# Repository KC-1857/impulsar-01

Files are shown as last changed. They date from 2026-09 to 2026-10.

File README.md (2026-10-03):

# Impulsar-01 — Local Home AI Station


[]()

[Русская версия](README-RU.md)

Open-source home AI station: a voice assistant and smart home control on a single-board computer.

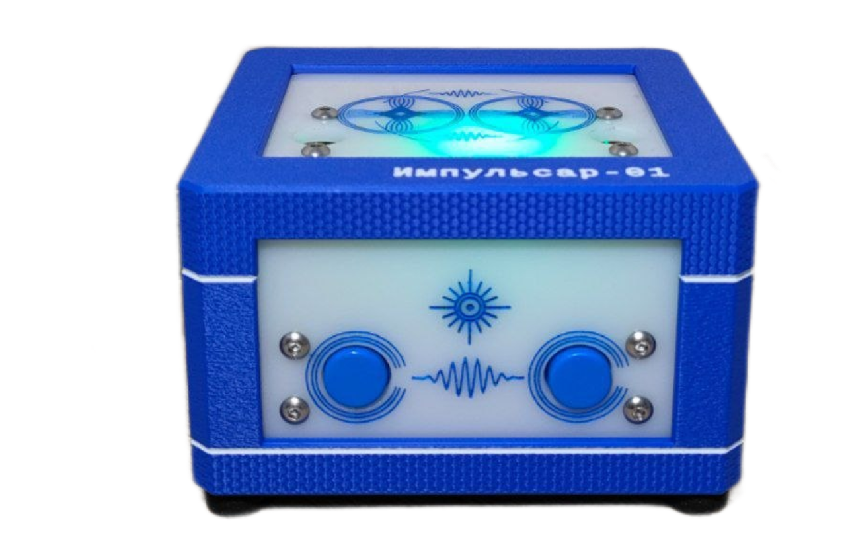
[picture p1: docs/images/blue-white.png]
Prototype


## Features

- On-device Russian speech recognition in real time
- Voice control of Zigbee devices using a fixed command vocabulary
- LED status indication (listening, command, ready, error)
- Event log for monitoring and diagnostics

## Hardware

- Orange Pi CM4 (Rockchip RK3566) single-board computer
- Microphone expansion board
- USB Zigbee coordinator

## Enclosure

[Rev06 enclosure](mechanical/impulsar-01-rev06/README.md): printable STL, laser-cut
acrylic DXF/SVG, fit-test coupons, an editable FreeCAD model, STEP exports and
standalone generators. The variant directory includes all source geometry and can
be built independently, without printer-specific profiles. See the [manufacturing guide](mechanical/impulsar-01-rev06/MANUFACTURING.md)
and [enclosure catalogue](mechanical/README.md). Physical fit, cooling and drop
resistance still require prototype testing.

## Documentation

Project documentation lives in [`docs/`](docs/):

- [Vision & Scope](docs/vision-ru.md) — product vision, MVP scope, success criteria
- [SRS](docs/srs-ru.md) — technical specification: requirements, use cases, acceptance tests
- [Backlog](docs/backlog-ru.md) — user stories with priorities and estimates
- [User story map](docs/user-story-map-ru.md) — scenarios and MVP slice
- [Hardware reference](docs/hardware-ru.md) — Orange Pi CM4 platform details
- [Glossary](docs/glossary-ru.md) — hardware terms
- [Diagrams](docs/diagrams/) — PlantUML sources (context, use cases, components)

## Image

The working image is available via the link:

[Image link](https://drive.google.com/file/d/1G7m_2_bZuDXotqwk8EMmxWDe1scBuL78/view)

## Contributing

Please read [CONTRIBUTING.md](CONTRIBUTING.md) before submitting changes.

## License

Licensed under [GPL-3.0](LICENSE).

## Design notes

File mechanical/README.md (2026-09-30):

# Корпуса Импульсар-01

| Вариант | Назначение |
| --- | --- |
| [Northern lights — 01](Northern%20lights%20-%2001/) | Исходные STL и DXF первого корпуса |
| [Импульсар-01 rev06](impulsar-01-rev06/README.md) | Самодостаточный вариант: корпус 102 × 95 × 60 мм, акрил 2,85 мм, винтовая сборка; исходники, генераторы, STL, лазерные контуры, пробники и FreeCAD |

Готовность файлов к цифровой обработке не означает выполнения приёмки корпуса
по [SRS §4.3.8 и TC-05](../docs/srs-ru.md). Компоновку электроники, доступ
к разъёмам, охлаждение и прочность необходимо проверить на собранном образце.

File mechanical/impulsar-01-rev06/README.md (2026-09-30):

# Импульсар-01 — корпус rev06

Корпус **102 × 95 × 60 мм**: три печатные детали, пять панелей акрила **2,85 мм**,
пазы **3,00 мм**, два винта M3×50 и съёмная планка верхнего акрила.

Самодостаточный вариант корпуса: каталог содержит исходные данные, параметры,
генераторы и контрольные модели этого дизайна. Его можно скопировать отдельно
и собрать без остальных каталогов проекта. Геометрия не привязана к модели
принтера, размеру его рабочего поля или конкретному слайсеру.

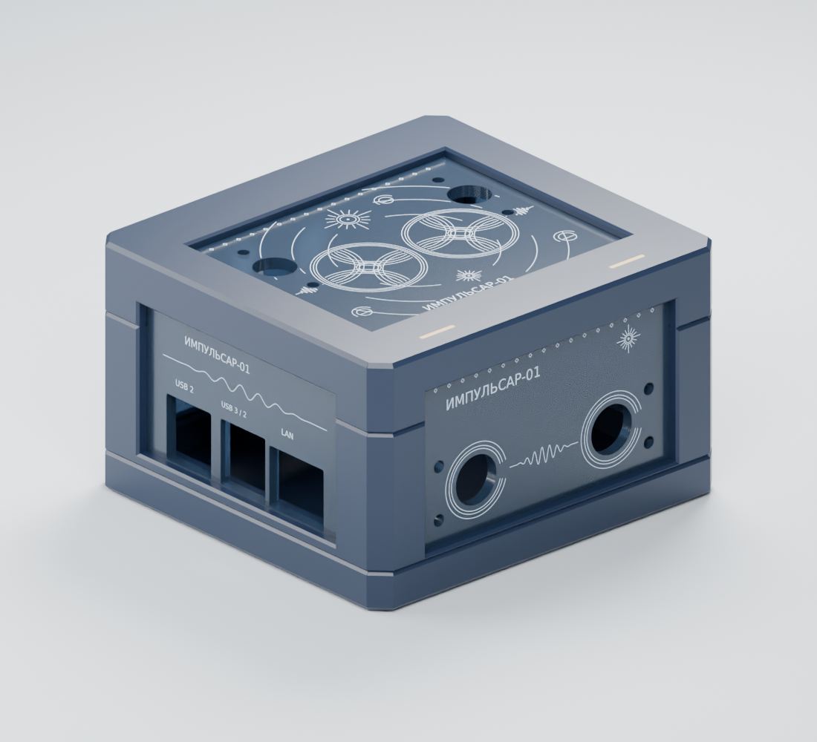
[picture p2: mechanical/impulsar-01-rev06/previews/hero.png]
Корпус rev06


## Что открыть

- **Для изготовления:** [инструкция и крепёж](MANUFACTURING.md), [STL для печати](print/),
  [пробники](coupons/), [лазерные DXF/SVG](laser/), [многоцветная крышка 3MF](multicolor/lid_multicolor.3mf).
- **Для редактирования:** [FreeCAD](cad/enclosure.FCStd), [нейтральные STEP](cad/step/),
  [вид нативной CAD-модели](cad/preview.png).
- **Для просмотра:** [3D-сборка GLB](assembly/impulsar06.glb), [разнесённый вид](previews/exploded.png).
- **Конструкция и исходные данные:** [DESIGN.md](DESIGN.md).
- **Результаты проверки:** [STL, FreeCAD и STEP](validation/README.md).

`print/`, `assembly/`, `coupons/`, `laser/`, `multicolor/` и изображения — контрольный комплект
корпуса Импульсар-01 rev06. Его хеши записаны в [reference/assets.sha256.json](reference/assets.sha256.json).
`assembly/` содержит координаты сборки, **не ориентации для печати**.

## Автономная пересборка

Команды выполняются **из этого каталога `impulsar-01-rev06/`**. Все исходные данные
находятся внутри него; доступ к сети при сборке не требуется. Зависимости
устанавливаются заранее:

```bash
python3 -m venv .venv
.venv/bin/python -m pip install -r requirements.txt
.venv/bin/python src/build_mesh.py
```

Результат: локальный `build/mesh/` — сборочные и печатные STL, пробники, многоцветный 3MF,
копии лазерных контуров, параметры, сравнение с исходником и новый отчёт проверок.
Превью и GLB являются сохранёнными иллюстрациями корпуса rev06; сборщик их
не обновляет. После изменения конструкции они могут перестать соответствовать ей.

Параметры задаются в [design.json](design.json). Для экспериментов используйте
копию и `--config путь/к/design.json --output build/мой-вариант`.
`parameters.json` в результатах — отчёт, а не входной файл. Лазерные контуры являются
входными исходниками; изменение толщины не меняет их плоскую геометрию и имена.
После изменения толщины обозначения `2p85` требуют отдельного обновления.

Пути к исходникам и результатам по умолчанию определяются относительно каталога
варианта, независимо от текущего рабочего каталога. Генераторы разрешают вывод
в локальный `build/` или отдельный внешний каталог и защищают исходные данные
и готовый комплект от перезаписи.
Обновление готовых файлов выполняется после проверки результатов и просмотра diff.

## FreeCAD

Требуется FreeCAD **1.1.x** с Python API. Проверено на FreeCAD 1.1.3 / Python 3.14.
Интерпретатор должен совпадать с Python ABI установленного FreeCAD.
Пример для ALT Linux (путь библиотеки в других дистрибутивах отличается):

```bash
PYTHONPATH=/usr/lib64/freecad/lib .venv/bin/python src/build_cad.py
```

Результат: `build/cad/` — `enclosure.FCStd`, STEP отдельных деталей
и сборки, STL из той же CAD-геометрии в сборочных и печатных координатах.
Пересчёт дерева из нескольких сотен операций может занять десятки минут.

Модель содержит нативные эскизы, выдавливания, лофты, цилиндры и булевы операции.
Открытие и редактирование FCStd не требуют установки скриптов проекта.
В таблице **Parameters**, столбец B, доступны толщина акрила, ширина пазов,
радиусы проходных отверстий, отверстий планки и направляющих саморезов.
После изменения выполнить пересчёт документа. Геометрия крепежа — номинальные
огибающие без резьбы. Контуры панелей редактируются в исходных DXF и пересобираются.

CAD восстановлена по исходным STL и измеренным плоским сечениям: это отдельное
параметрическое представление rev06. Круглые элементы CAD аналитические, поэтому
они могут немного отличаться от исходной полигональной аппроксимации.
Оригинальные производственные STL сохранены отдельно от экспортов CAD.
Изменения в GUI FreeCAD **не записываются автоматически в design.json или Python**;
для воспроизводимой правки перенесите значения в конфигурацию/генератор.

## Проверки и физическая приёмка

Сборщик STL проверяет замкнутость и связность сеток, разницу объёмов с исходником,
сопряжения деталей, проход крепежа, дискретные траектории снятия крышки и установки
панелей, удержание верхнего акрила, ожидаемый натяг саморезов и входа гаек.
Отчёты контрольного комплекта находятся в `validation/`, новые создаются в `build/`.

После генерации CAD проверьте повторное открытие FCStd, импорт STEP, сетки,
сравнение с исходником и сопряжения. `--edit-check` дополнительно меняет пять
размеров таблицы и пересчитывает документ; тестовые изменения не сохраняются:

```bash
PYTHONPATH=/usr/lib64/freecad/lib .venv/bin/python src/verify_cad.py --edit-check
```

Цвета и прозрачность готового FCStd настроены в GUI FreeCAD; генератор воспроизводит
геометрию и дерево операций. Превью CAD также сохраняется отдельно от геометрии.

Проверка контрольных сумм, исходных сеток и многоцветного 3MF:

```bash
.venv/bin/python src/verify_assets.py
```

Отчёт создаётся в `build/audit/`.

Статус физической посадки: **не подтверждена**. Окна CM4 оценены по фотографии;
начните с пробника панели и узлов крепления. Полная электроника, провода и охлаждение
не представлены в сборке. Тепловые испытания и падение с 1 м не проводились.
Цифровые проверки подтверждают геометрию, но не заменяют испытаний собранного корпуса.

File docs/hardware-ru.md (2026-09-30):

# Одноплатный компьютер Orange Pi CM4 (RK3566) — справочник по аппаратной части

Версия документа: 0.2

Назначение: справочная информация по аппаратной платформе стенда — базовой плате Orange Pi, модулю CM4 (SoM) и SoC Rockchip RK3566.
Требования к Системе — в [docs/srs-ru.md](./srs-ru.md)

Механическая часть: [корпус rev06](../mechanical/impulsar-01-rev06/README.md),
модели FreeCAD/STEP, STL, лазерные контуры и инструкция изготовления.
Компоновка полной электроники и охлаждение требуют проверки на прототипе.

## 1. Глоссарий

- eDP (Embedded DisplayPort) – интерфейс для внутренних дисплеев, выведен на дополнительные контакты модуля CM4, но не на базовую плату;
- MIPI DSI (Display Serial Interface) – скоростной интерфейс для подключения дисплеев; на RK3566 доступны 4 линии, но базовая плата разводит только 2
- MIPI CSI (Camera Serial Interface) – интерфейс для подключения камер, аналогично DSI, на базовой плате выведено 2 линии
- PMIC (Power Management Integrated Circuit) – микросхема управления питанием, на модуле CM4 используется RK809-5
- TRM (Technical Reference Manual) – техническое руководство по процессору, содержащее детальное описание регистров, блоков и программирования
- VPU (Video Processing Unit) – блок для ускорения кодирования и декодирования видео; в RK3566: декодирование до 4K@60fps (H.265/H.264/VP9), кодирование до 1080p@60fps

## 2. Спецификация

### 2.1. Базовая плата Orange (Base Board)
| Компонент | Характеристика |
|---|---|
| **Видеовыходы**| 1× Micro HDMI 2.0 (4K@60fps), 1× MIPI DSI (2 линии) |
| **Камера** | 2× MIPI CSI (2 линии каждый) |
| **Сеть** | 1× Gigabit Ethernet (RJ45) |
| **USB** | 1× USB 3.0 Host, 2× USB 2.0 Host, 1× USB 2.0 OTG |
| **Хранилище** | Слот MicroSD (TF), разъём M.2 M-Key (SATA3 или PCIe 2.0 ×1 NVMe) |
| **Аудио** | 3.5 мм комбинированный разъём (вход/выход) |
| **Расширение** | 40-контактная колодка (GPIO, UART, I2C, SPI, PWM); напряжение 1.8 В или 3.3 В (переключается джампером) |
| **Охлаждение** | 4-контактный разъём для вентилятора (5 В) |
| **Кнопки** | MASKROM, RECOVERY, RESET |
| **Питание** | USB Type-C, 5 В / 3 А |
| **Размеры (PCB)** | 85 × 56 мм |
| **Масса** | 46 г |

### 2.2. Модуль Orange Pi CM4 (SoM)
| Компонент | Характеристика |
|---|---|
| **SoC** | Rockchip RK3566 |
| **Оперативная память**  | 2 ГБ LPDDR4 |
| **Встроенная память** | 8 ГБ eMMC |
| **Беспроводная связь**  | Wi-Fi 5 (802.11ac), Bluetooth 5.0 (чип AP6256) |
| **Ethernet PHY** | YT8531C (10/100/1000 Мбит/с) на модуле |
| **PMIC** | Rockchip RK809-5 |
| **Размеры (PCB)** | 55 × 40 мм |
| **Разъёмы** | 2× 100-контактных + 1× 24-контактный (совместимость с Raspberry Pi CM4 по основным сигналам) |
| **Выведенные сигналы**  | HDMI 2.0, MIPI DSI (4 линии), MIPI CSI (4 линии), eDP, SATA3/PCIe, USB 3.0, USB 2.0 (×3), аудио, GPIO|
| **Операционная система** | Linux (4.19.232) — стоковый BSP-образ вендора; целевая ОС проекта — ALT Linux, ядро 6.18 (SRS НФ-10.1) |

### 2.3. Чип: Rockchip RK3566

### 2.3.1. Общие сведения
| Параметр | Значение |
|---|---|
| **Модель** | Rockchip RK3566 |
| **Тип** | Система на кристалле (SoC) для мультимедийных и IoT-приложений |
| **Техпроцесс** | 22 нм |
| **Корпус** | BGA-565 (15.5 × 14.4 мм) |

### 2.3.2. Центральный процессор (CPU)
| Параметр | Значение |
|---|---|
| **Архитектура** | ARMv8-A (64-bit) |
| **Ядра** | 4 × Cortex-A55 |
| **Максимальная частота** | 1.8 ГГц |

### 2.3.3. Графический процессор (GPU)
| Параметр | Значение |
|---|---|
| **Модель** | ARM Mali-G52 2EE |
| **API** | OpenGL ES 1.1/2.0/3.2, OpenCL 2.0, Vulkan 1.1 |
| **2D-ускорение** | Встроенный аппаратный 2D-ускоритель |

### 2.3.4. Видеопроцессор (VPU)
| Параметр | Значение |
|---|---|
| **Декодирование** | 4K@60fps (H.265/HEVC, H.264, VP9) |
| **Кодирование** | 1080p@60fps (H.265/H.264) |

### 2.3.5. Нейронный процессор (NPU)
| Параметр | Значение |
|---|---|
| **Модель** | RKNN NPU |
| **Производительность** | 0.8 TOPS (INT8) |
| **Поддерживаемые фреймворки** | Caffe, TensorFlow, TFLite, ONNX, PyTorch, Keras, Darknet |

### 2.3.6. Интерфейсы памяти и хранения
| Параметр | Значение |
|---|---|
| **Оперативная память** | DDR3/DDR3L/DDR4, LPDDR3/LPDDR4/LPDDR4X (до 8 ГБ) |
| **Хранилище** | eMMC 5.1, SATA 3.0, SPI NOR/NAND Flash |

### 2.3.7. Высокоскоростные интерфейсы
| Интерфейс | Характеристика |
|---|---|
| **Дисплей** | HDMI 2.0a (4K@60), MIPI DSI (4 линии), eDP 1.3, RGB/LVDS; поддержка двух независимых дисплеев |
| **Камера** | MIPI CSI (4 линии / 2×2 линии), 8M ISP с HDR |
| **PCIe** | PCIe 2.1 ×1 (1 линия) |
| **SATA** | SATA 3.0 (1 порт) |
| **USB** | 1× USB 3.0 Host, 2× USB 2.0 Host, 1× USB 2.0 OTG |
| **Ethernet** | 1× Gigabit Ethernet (GMAC) |
| **Аудио** | 8-канальный I2S/TDM, 2× 2-канальный I2S, 8-канальный PDM, S/PDIF выход |

### 2.3.8. Программная поддержка (со стороны чипа)
| ОС | Примечание |
|----|---|
| Android 11 | Официальный BSP от Rockchip |
| Linux (ядро 5.10 / 6.1) | BSP-ядро Rockchip с полной поддержкой NPU/VPU. Например, Linux 5.10.160-rockchip-rk356x под архитектуру arm64|
| Linux (mainline 6.6+) | Частичная поддержка (GPU — Panfrost; VPU/NPU — ограничены) |

### 2.4. Драйверы и прошивки

Состав драйверов и прошивок стенда (нормативные требования — [docs/srs-ru.md](./srs-ru.md), п. 4.3.9).

- WiFi (модуль AP6256, чип BCM4345/9): драйвер `brcmfmac`; файлы прошивки `/lib/firmware/brcm/brcmfmac43456-sdio.bin`, `brcmfmac43456-sdio.txt`, `brcmfmac43456-sdio.clm_blob`. Допускается обобщённая прошивка при совпадении ревизии чипа; board-specific файл `brcmfmac43456-sdio.xunlong,orangepi-cm4-v1.4.bin` не обязателен.
- Аудио (ReSpeaker 2-Mic HAT, WM8960): драйверы `snd-soc-wm8960` и кодек `wm8960`.
- SPI (APA102 LED HAT): драйвер `spidev`, устройство `/dev/spidev3.0`.
- GPIO (кнопка ASR): `gpiod`/libgpiod (userspace).

Проверка: `lsmod`, `dmesg`, `ls /lib/firmware/brcm`, `aplay -l`, `ls -l /dev/spidev3.0`, `python3 -c "import gpiod"` (в выводе `lsmod`/`dmesg` искать `brcmfmac`, `wm8960`, `spidev`).

Прошивки и проприетарные бинарные файлы в репозитории проекта не хранятся — поставляются в составе образа или пакетов.

## 3. Распиновка 40-контактной колодки (GPIO)

### 3.1. Пины SPI и сопутствующие

- 3 : GPIO4 B4 I2C2 SDA
- 5 : GPIO4 B5 I2C2 SCL

- 8  : UART2 TX
- 10 : UART2 RX

- 13 : GPIO 4 A0
- 15 : GPIO 4 A2
- 16 : GPIO 4 A3
- 18 : GPIO 4 A1
- 22 : GPIO 4 A4

- 19 : SPI3 MOSI 
- 21 : SPI3 MISO
- 23 : SPI3 CLK

- 24 : GPIO4 A6 / SPI3_CS0
- 26 : GPIO4_A7 / SPI3_CS1

- GND: 6, 9, 14, 20, 30, 34, 35, 39
- VCC: 1, 17

## 4. Ссылки

- Техническое руководство Rockchip RK3566 (TRM) — rockchip.fr / Rockchip Open Source wiki: https://opensource.rock-chips.com/wiki_RK3566
- Руководство пользователя Orange Pi CM4 — официальный сайт производителя: https://orangepi.org (раздел документации CM4)
- Сборка BSP Orange Pi — репозиторий orangepi-build: https://github.com/orangepi-xunlong/orangepi-build

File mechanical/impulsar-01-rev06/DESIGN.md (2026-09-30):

# Разработка корпуса Импульсар-01 rev06

Rev06 — вариант корпуса для проекта «Импульсар-01»: печатные основание, крышка
и съёмная планка, пять акриловых панелей и винтовое соединение половинок.

## Исходные данные

- Два базовых STL для построения основания и крышки находятся в `source/`.
  Их контрольные суммы сохранены в [reference/source.sha256.json](reference/source.sha256.json).
- [design.json](design.json) задаёт параметры генераторов rev06.
- `laser/` содержит плоские контуры резки и гравировки панелей.
- `src/source_profiles.json` хранит измеренные плоские сечения базовых STL.
  Они воспроизводятся командой
  `python3 src/extract_profiles.py` из каталога варианта;
  результат создаётся в локальном `build/profiles/`.

## Представления конструкции

`src/geometry.py` описывает конструкцию с двумя геометрическими реализациями:
сеточной для STL и нативной для FreeCAD. Модель FreeCAD содержит эскизы,
операции построения и связи с таблицей параметров. STEP и CAD-STL экспортируются
из одной и той же нативной геометрии.

Контрольный комплект изготовления находится в `print/`, `assembly/`, `coupons/`,
`laser/` и `multicolor/`; его параметры — в `reference/parameters.json`, контрольные
суммы 44 файлов комплекта и иллюстраций — в
[reference/assets.sha256.json](reference/assets.sha256.json).
Экспорты нативной модели хранятся отдельно в `cad/`; численные различия двух
представлений и результаты проверок приведены в [validation/](validation/README.md).

Дизайн включает тёмно-синие печатные детали, акриловые панели, гравировку
и два золотистых акцента на крышке. 3MF хранит геометрию и цвета трёх частей
крышки без настроек оборудования. Контуры гравировки находятся в `laser/`.

Каталог самодостаточен после установки зависимостей: соседние варианты корпуса
и корень репозитория для сборки не используются. Команды и порядок изменения
параметров приведены в [README](README.md), изготовление и сборка — в
[MANUFACTURING.md](MANUFACTURING.md).

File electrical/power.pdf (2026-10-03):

V+ | GND
1 | 2

X1

V+ | GND
1 | 2

X2

SA1

Рисунок 1 – Схема электрическая подключения клеммных блоков X1 и X2

## ПЕРЕЧЕНЬ ЭЛЕМЕНТОВ

Поз. обозначение | Наименование | Кол. | Примечание
X1, X2 | Клеммный блок 2-контактный | 2
SA1 | Выключатель кнопочный | 1

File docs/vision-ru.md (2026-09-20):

# Видение и границы проекта (Vision & Scope)

Версия документа: 0.1 

 Связанные документы: 

 [SRS (техническое задание)](./srs-ru.md), 

 [Бэклог](./backlog-ru.md), 

 [Карта пользовательских историй](./user-story-map-ru.md)

## 1. Введение

### 1.1. История контекста

Коммерческие домашние голосовые ассистенты построены на проприетарных облачных сервисах. Устройство записывает речь пользователя, но обрабатывают голос сервера производителя. Логика исполнения сценариев прописана в закрытой экосистеме. Работоспособность устройства зависит от доступности облака и оплаченной подписки. Для пользователя это означает невозможность работать с устройством без интернета и абонентской платы.

Технически задача сводится к запуску модели распознавания речи и обработке команд. Одноплатный компьютер подбирается под минимальную мощность, достаточную для распознавания речи на открытых моделях (GigaAM, Whisper). Поддержка открытого протокола Zigbee позволяет управлять устройствами "умного" дома. Одно из ограничительных условий проекта - минимальная стоимость комплектующих.

Для реализации программной части полезно использовать минимально необходимую проектную документацию, включая требования и сценарии использования. 

### 1.2. Постановка проблемы

В сообществе открытых проектов существуют продукты класса "Домашняя станция". Данный продукт решает следующие проблемы:

- адаптация под условия России: доступные компоненты электроники, лицензии на программы, модели распознавания русской речи;
- минимальная коммерческая стоимость продукта и возможность собрать его своими руками;
- формализованные требования и документация;

### 1.3. Цель документа

Определить видение продукта, его границы, заинтересованные стороны, потребности верхнего уровня, ограничения и критерии успеха. Детальные
требования фиксируются в SRS ([docs/srs-ru.md](./srs-ru.md)), план работ — в бэклоге ([docs/backlog-ru.md](./backlog-ru.md)) и карте пользовательских историй ([docs/user-story-map-ru.md](./user-story-map-ru.md)).

## 2. Видение продукта

### 2.1. Формулировка видения

Пользователь получает устройство с голосовым, кнопочным и электронным интерфейсом для управления Zigbee-устройствами. Первый релиз — портированная на одноплатный SoC система с микрофонным модулем, с установкой компонентов в корпус.

### 2.2. Минимальное рабочее решение (MVP)

Обязательные компоненты MVP:

1. Embedded Linux на одноплатном компьютере;
2. Детекция речевой активности;
3. Распознавание речевых команд в реальном времени;
4. Интеграция с Zigbee-протоколом через USB-адаптер;
5. Закрытый корпус с выводом физических (кнопки, LED), голосовых (микрофонный модуль), электронных (USB) интерфейсов;

## 3. Заинтересованные стороны и пользователи

### 3.1. Заинтересованные стороны

- мейнтейнер проекта;
- технические энтузиасты;
- opensource-сообщество;
- контрибьюторы (участники) проекта;
- пользователи AI-станции;
- поставщики компонент железа (SoC, модули);
- upstream AI-моделей;
- upstream ОС;

### 3.2. Пользовательские роли

- пользователь — говорит команды;
- администратор — проводит диагностику;
- разработчик — собирает проект, вносит изменения.

## 4. Потребности и функции верхнего уровня

- Ф1. Локальное распознавание речи: Система должна распознавать команды в реальном времени;
- Ф2. Дальняя и тихая речь: Система должна распознавать речь на дистанции от 1 до 5 м;
- Ф3. Управление Zigbee-устройствами:
  - Ф3.1. Система должна сопоставлять распознанный текст командам из словаря;
  - Ф3.2. Система должна исполнять команду на исполнительном устройстве (реле, лампы, датчики) с поддержкой Zegbee-протокола;
- Ф4. Индикация состояния: Система должна индицировать фазы работы светодиодом;
- Ф5. Автономность:
  - Ф5.1. Система должна самовосстанавливаться после сбоев;
  - Ф5.2. Система должна работать без подключения к Интернет;

## 5. Ограничения продукта

- Платформа: Orange Pi CM4, SoC RK3566 (4 ядра ARM Cortex-A55, GPU Mali-G52), ASR выполняется на CPU, тяжёлые модели не применяются;
- ОС: семейство ALT Linux (embedded-сборка), ядро 6.18;
- Память и накопитель: объём ОЗУ и eMMC/MicroSD ограничен;
- Аудиотракт: ReSpeaker 2-Mic Pi HAT (кодек WM8960); характеристики микрофонной матрицы задают дальность распознавания; шумоподавление — программное;
- Zigbee: поддержка адаптера;
- Лицензии: GPLv3 и совместимые лицензии; модели с лицензиями, допускающими использование в продукте;
- Бюджет: минимальная стоимость компонент;
- Портирование на другие SoC в текущем MVP не предполагается;
- Многопользовательская идентификация по голосу отсутствует;
- Доступ в интернет отсутствует;
- Веб-интерфейс отсутствует, только VUI;
- Выход звука отсутствует;
- Синтез речи отсутствует;
- LLM отсутствует;

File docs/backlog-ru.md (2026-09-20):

# Бэклог пользовательских историй

Версия документа: 0.1

Связанные документы: [Видение и границы](./vision-ru.md), [SRS](./srs-ru.md),
[Карта историй](./user-story-map-ru.md)

## 1. Назначение и правила ведения

Бэклог — упорядоченный список историй. Правила:
- Детализация средняя; истории оценимы, к ним поставлены приоритеты; бэклог заполняется из обратной связи;
- Каждая история небольшая, независит от других историй, несет ценность для пользователя, тестируемая;
- Приоритизация: Must — без истории релиз не выполним; Should — важная, но релиз возможен без неё; Could — желательная; Won't — исключена из текущих релизов;
- Готовность: критерии приёмки выполнены, результат зафиксирован в CHANGELOG, требования SRS не противоречат реализации;
- Статусы: готово (история реализована), в работе (историю взял в работу контрибьютер), бэклог (ожидает контрибьютера), на паузе, тест (история выполнена, ждет проверки);

## 2. Истории

### 2.1 Подготовка станции

- US-1.1. Развернуть образ ОС.
  Как администратор, я хочу развернуть образ ALT Linux (ядро 6.18) на CM4, чтобы запустить исполняемый код.
  Приоритет Must
  Статус: готово

- US-1.2. Активировать DTB микрофонного модуля.
  Как администратор, я хочу активировать DTB ReSpeaker 2-Mic, чтобы появилась запись звука.
  Приоритет Must
  Статус: готово

- US-1.3. Параметры усиления подготовлены для микрофонного модуля.
  Как пользователь, я хочу, чтобы система автоматически применяла заранее подобранные параметры усиления, чтобы речь распознавалась с максимальным качеством.
  Приоритет Must
  Статус: готово

- US-1.4. Интеграция Zigbee.
  Как администратор, я хочу интегрировать устройство через USB-адаптер, чтобы управлять голосом.
  Приоритет Must
  Статус: в работе

- US-1.5. Обновление прошивки.
  Как пользователь, я хочу обновлять прошивку через USB-накопитель.
  Приоритет Must
  Статус: бэклог

### 2.2 Запуск и работа

- US-2.1. Автозапуск и восстановление.
  Как пользователь, я хочу, чтобы сервисы стартовали автоматически и перезапускались после сбоя, чтобы станция была автономной.
  Приоритет Must
  Статус: в работе

- US-2.2 Индикация фаз.
  Как пользователь, я хочу видеть фазу работы на LED (слушаю/распознаю/команда/ошибка), чтобы понимать состояние станции.
  Приоритет Must
  Статус: в работе

### 2.3 Распознавание речи

- US-3.1. Непрерывное прослушивание.
  Как пользователь, я хочу, чтобы станция непрерывно слушала микрофон и выделяла речь (VAD, порог 0.2)
  Приоритет Must
  Статус: в работе

- US-3.2. Локальное распознавание.
  Как пользователь, я хочу локальное распознавание в реальном времени (GigaAM ONNX на CPU)
  Приоритет Must
  Статус: в работе

- US-3.3. Тихий голос.
  Как пользователь, я хочу произносить команды тихим голосом с расстояния ≥ 1 м.
  Приоритет Should
  Статус: в работе

### 2.4 Голосовое управление

- US-4.1. Управление светом
  Как пользователь, я хочу управлять светом - командами «включить свет» и «выключить свет».
  Приоритет Must
  Статус: в работе

  Критерии приёмки:

  Функция: Исполнение голосовой команды «включи свет»
  Сценарий: успешное включение
    Дано: станция активна, сервисы запущены, реле выключено
    Когда пользователь с расстояния до 5 м произносит «включить свет»,
    Тогда интерпретатор сопоставляет текст команде «свет.включить»,
    И Zigbee-адаптер отправляет команду на реле.
    Реле включается не позднее чем через 10 с после конца фразы (НФ-16.1).
    LED включает свет для фазы «команда», событие записывается в журнал

- US-4.2. Защита от ложных срабатываний.
  Как пользователь, я хочу, чтобы посторонние слова не исполняли команды.
  Приоритет Must
  Статус: в работе

  Критерии приёмки:

  Функция: Отклонение фраз вне словаря
  Сценарий: фраза вне словаря
    Дано: станция слушает
    Когда пользователь произносит «какая сегодня погода»,
    Тогда команда не исполняется.
    Событие записывается в журнал как нераспознанное

### 2.5 Контроль и диагностика

- US-5.1. Журнал событий.
  Как оператор, я хочу видеть журнал (команда/время/результат), чтобы контролировать работу станции.
  Приоритет Must
  Статус: в работе

### 2.6 Сопровождение

- US-6.1. Документация требований.
  Как контрибьютор, я хочу иметь документацию Vision/SRS, чтобы разобраться в проекте.
  Приоритет Must
  Статус: в работе

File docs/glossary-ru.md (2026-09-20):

# Глоссарий проекта «Домашняя AI-станция» (аппаратная часть)

Версия документа: 0.1

Термины аппаратной платформы стенда (Orange Pi CM4, SoC Rockchip RK3566).
Термины и сокращения Системы — в [docs/srs-ru.md](./srs-ru.md)

## 1. Глоссарий

- BootROM (Bootstrap ROM, Boot Read-Only Memory, ROM code) — неизменяемый код начальной загрузки, записанный в постоянную память (Read-Only Memory) процессора. Сразу при подаче питания процессор начинает выполнять этот код. Микропрограмму BootROM записывает производитель чипа;
- BSP (Board Support Package) – пакет программного обеспечения, включающий ядро, драйверы и конфигурации для конкретной платы, обычно предоставляемый производителем чипа;
- Device Tree - описание аппаратной конфигурации Linux;
- DRAM (Dynamic RAM) - внешняя динамическая оперативная память (например, DDR4, LPDDR4X), требующая сложной инициализации контроллера памяти;
- Embedded Linux - концепция дистрибутива для управления устройствами. Обычно включает: загрузчик, ядро Linux, корневую файловую систему, утилиты, библиотеки, службы;
- eMMC (Embedded MultiMediaCard) – встроенная флеш-память для хранения системы и данных (8 ГБ на модуле CM4);
- GPIO - (General-Purpose Input/Output) - интерфейс ввода/вывода общего назначения;
- Idbloader - предзагрузчик Rockchip, содержащий DDR init + SPL/TPL;
- LBA (Logical Block Addressing) — способ адресации блоков на диске или SD-карте;
- M.2 M-Key – разъём на базовой плате, поддерживающий NVMe (через PCIe x1) или SATA-накопители;
- Mask ROM - тип постоянной памяти, содержимое которой создается на этапе производства микросхемы с помощью фотошаблона (маски). Физически невозможно изменить после изготовления;
- Mask ROM Mode - аварийный режим BootROM загрузки. BootRom переходит в этот режим, если не может найти корректный загрузчик ни на одном из носителей. В этом режиме чип ожидает команды от хоста по USB;
- NPU (Neural Processing Unit) – аппаратный ускоритель для операций машинного обучения
- PCIe (Peripheral Component Interconnect Express) – интерфейс для подключения скоростной периферии
- Rockusb - USB-протокол Rockchip для загрузки/прошивки; используется для низкоуровневого взаимодействия с BootRom (в MaskRom-режиме) и загрузчиками для прошивки и восстановления устройств;
- SATA (Serial ATA) – интерфейс для подключения накопителей;
- SDMMC - интерфейс SD-карт/MMC;
- Secure Boot - цепочка доверенной загрузки с проверкой подписи;
- SoC (System on Chip) - микросхема, интегрирующая процессор, графику, контроллеры памяти и периферийные интерфейсы на одном кристалле;
- SoM (System-on-a-Module, SoM) — архитектура компьютерной системы, при которой на одной печатной плате располагаются все необходимые для работы подсистемы;
- SPL (Secondary Program Loader) - вторичный загрузчик; код в ПЗУ загружает SPL в SRAM (небольшая область статической памяти); SPL настраивает контроллер памяти и др. части системы; SPL переходит на начало TPL (третичный загрузчик) - например, u-boot.bin, загружает TPL в DRAM;
- SRAM (Static RAM) - внутренняя статическая оперативная память чипа, доступная сразу после подачи питания. BootRom использует ее как временное хранилище для стека и выполнения кода до инициализации основной DRAM;
- TPL (Third stage program loader) - третичный загрузчик; загружает ядро операционной системы в SDRAM;
- UART - (Universal Asynchronous Receiver-Transmitter) - протокол передачи данных. Например, RS-232;
- U-Boot - начальный загрузчик ядра операционной системы;

## 2. Источники

1. [Исходный код - репозиторий сборки OrangePi-build](https://github.com/orangepi-xunlong/orangepi-build)
2. [Официальный сайт - характеристика платы](http://www.orangepi.org/html/hardWare/computerAndMicrocontrollers/details/Orange-Pi-CM4-1.html)
3. [U-Boot поддержка Rockchip](https://docs.u-boot.org/en/v2023.10/board/rockchip/rockchip.html)

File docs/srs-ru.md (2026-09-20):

# Техническое задание на систему «Домашняя AI-станция» (SRS)

Версия документа: 0.1

Связанные документы:

[Видение и границы](./vision-ru.md), [Бэклог](./backlog-ru.md), [Карта пользовательских историй](./user-story-map-ru.md).

Содержание

## 1. Общие сведения

### 1.1. Полное и краткое наименование системы

- Полное наименование: автоматизированная система локального распознавания речи и голосового управления устройствами с поддержкой протокола Zigbee «Домашняя AI-станция».
- Краткое наименование: Домашняя AI-станция (далее — Система, АС).

### 1.2. Заказчик и разработчик

- разработчик: <сообщество проекта>;
- модель разработки: OpenSource;

### 1.3. Перечень документов, на основании которых создаётся Система

- ГОСТ 34.602-2020 «Информационная технология. Комплекс стандартов на автоматизированные системы. Техническое задание на создание автоматизированной системы»;
- [docs/vision-ru.md](./vision-ru.md) — видение и границы проекта;
- документация Orange Pi CM4 (Rockchip RK3566);

### 1.4. Термины и сокращения

- ASR (Automatic Speech Recognition) — распознавание речи;
- STT (Speech-to-Text) — перевод речи в текст;
- GigaAM — открытая русская ASR-модель;
- VAD (Voice Activity Detection) — детекция речевой активности;
- Zigbee — открытый протокол беспроводной сети устройств малого радиуса;
- HAT (Hardware Attached on Top) — плата расширения на 40-контактном разъёме;
- Интент — распознанное намерение пользователя (действие + параметры);
- DTB (Device Tree Blob) — скомпилированное описание устройств платформы;
- ФТ — функциональное требование; НФ-требование — нефункциональное требование;
- UC (Use Case) — сценарий использования системы;
- Логическая модель данных — представление сущностей данных и связей между ними без привязки к физической реализации хранения.

## 2. Назначение и цели создания Системы

### 2.1. Назначение Системы

Система предназначена для управления устройствами Zigbee через голосовой интерфейс.

### 2.2. Ожидаемые цели создания

- Ц1. Обеспечить автономное распознавание речи на одноплатном компьютере Orange Pi CM4 (SoC RK3566) под управлением Embedded Linux.
- Ц2. Реализовать управление устройствами Zigbee голосовыми командами из фиксированного словаря.

## 3. Характеристика Системы

### 3.1. Описание Системы

Система — модуль с голосовым интерфейсом для приема команд и управления исполнительными устройствами(реле, лампы, датчики) через интерфейс Zigbee.

### 3.2. Контекст

Контекстная диаграмма: Система и внешние сущности с информационными потоками
между ними.

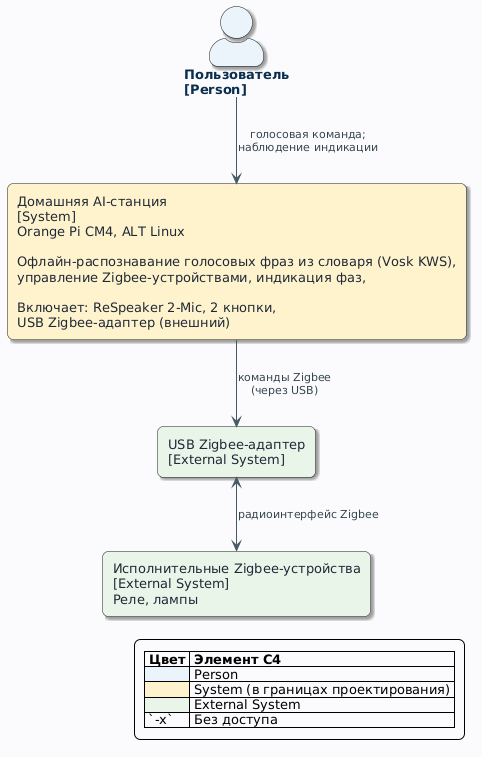
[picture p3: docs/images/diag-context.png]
Контекстная диаграмма «Домашняя AI-станция»


Исходный код диаграммы: [diag-context.uml](./diagrams/diag-context.uml).

### 3.3. Сценарии использования (Use case)

Сценарии использования Системы.

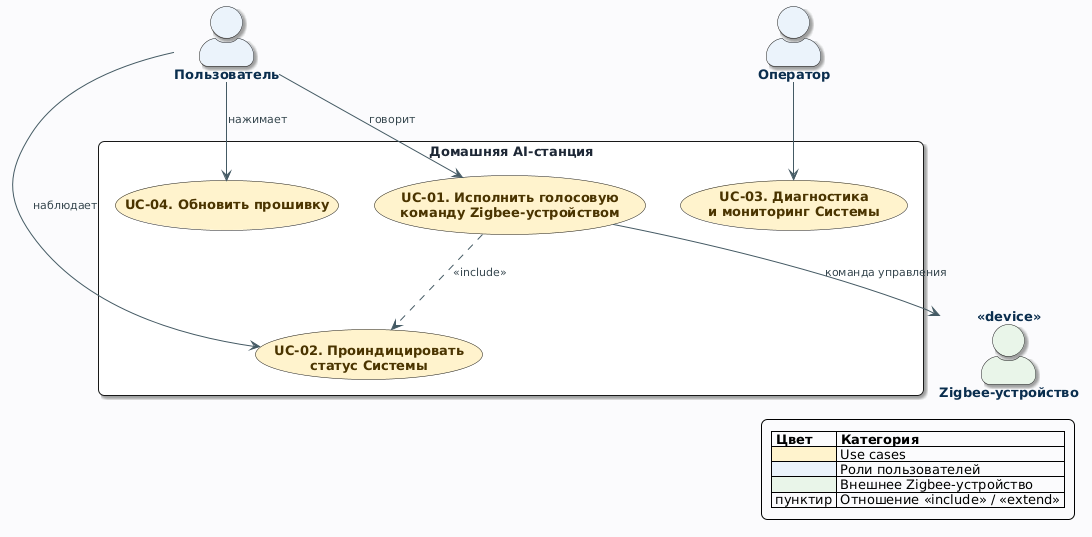
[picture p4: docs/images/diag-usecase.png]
Диаграмма сценариев использования (Use case)

Общая диаграмма сценариев — код PlantUML: [diag-usecase.uml](./diagrams/diag-usecase.uml).

#### UC-01. Исполнить голосовую команду Zigbee-устройством

| Поле | Содержание |
|---|---|
| Актор | Пользователь (основной); Zigbee-устройство (вторичный) |
| Триггер | пользователь произносит команду из словаря |
| Предусловие | Система запущена, сервисы активны; Zigbee-адаптер работоспособен; |
| Основной поток | 1. П1 захватывает аудиопоток. 2. П2 детектирует речевой сегмент. 3. Система переводит фазу в «распознаю»; П3 выдаёт транскрипт сегмента в реальном времени; выполняется UC-02. 4. П6 нормализует текст и вычисляет процент совпадения с командой словаря. 5. Процент ≥ порогу подтверждения: П6 инициирует событие управления; Система переводит фазу в «команда»; выполняется UC-02. 6. П7 исполняет действие на целевом устройстве. 7. Система фиксирует в журнале событие управления. 8. Постусловие достигнуто |
| Альтернативные потоки | 2a. Речевой сегмент не обнаружен — возврат к шагу 1. 4a. Процент совпадения ниже порога подтверждения — фраза игнорируется, событие управления не порождается. 6a. Устройство недоступно — Система переводит фазу в «ошибка», выполняется UC-02; в журнал фиксируется «ошибка» |
| Постусловие | При успехе: состояние Zigbee-устройства изменено; событие управления зафиксировано в журнале. При 6a: состояние Zigbee-устройства не изменено; ошибка зафиксирована в журнале |

#### UC-02. Проиндицировать статус Системы

| Поле | Содержание |
|---|---|
| Актор | Пользователь (вторичный) |
| Триггер | Смена фазы Системы на индицируемую: «распознаю», «команда», «ошибка». Фаза «слушаю» светодиодами не отображается |
| Предусловие | Система запущена; журнал доступен; задана таблица соответствия фазы и светодиода (см. п. 4.1, П4); все три светодиода работоспособны |
| Основной поток | 1. Система определяет текущую фазу 2. П4 включает светодиод, закреплённый за фазой, в заданном режиме. 3. Система фиксирует фазу в журнале |
| Альтернативные потоки |  |
| Постусловие | Текущая фаза отображена доступными средствами индикации; событие зафиксировано в журнале |

#### UC-03. Диагностика и мониторинг Системы

| Поле | Содержание |
|---|---|
| Актор | Оператор |
| Триггер | подозрение на сбой, плановая проверка |
| Предусловие | доступ по SSH; диагностические скрипты установлены; журнал systemd доступен; у Оператора есть права на чтение журнала |
| Основной поток | 1. Оператор запускает скрипт диагностики аппаратуры: аудио, DTB. 2. Система выдаёт состояние аппаратуры. 3. Оператор просматривает журнал systemd: события работы и событий управления |
| Альтернативные потоки | 3а. Журнал не сохранил запись событий |
| Постусловие | Состояние аппаратуры проверено; инциденты отражены в журнале;  |

#### UC-04. Обновление прошивки (черновик)

| Поле | Содержание |
|---|---|
| Актор | Пользователь |
| Триггер |  |
| Предусловие | Прошивка записана на USB-носитель; USB-носитель физически установлен в порт; USB-носитель не поврежден |
| Основной поток | 1. Пользователь нажимает кнопку 1 на интерфейсе |
| Альтернативные потоки |  |
| Постусловие | Обновление завершено; Статус обновления проиндуцирован светодиодом; Событие обновления записано в журнале; |

## 4. Требования к Системе

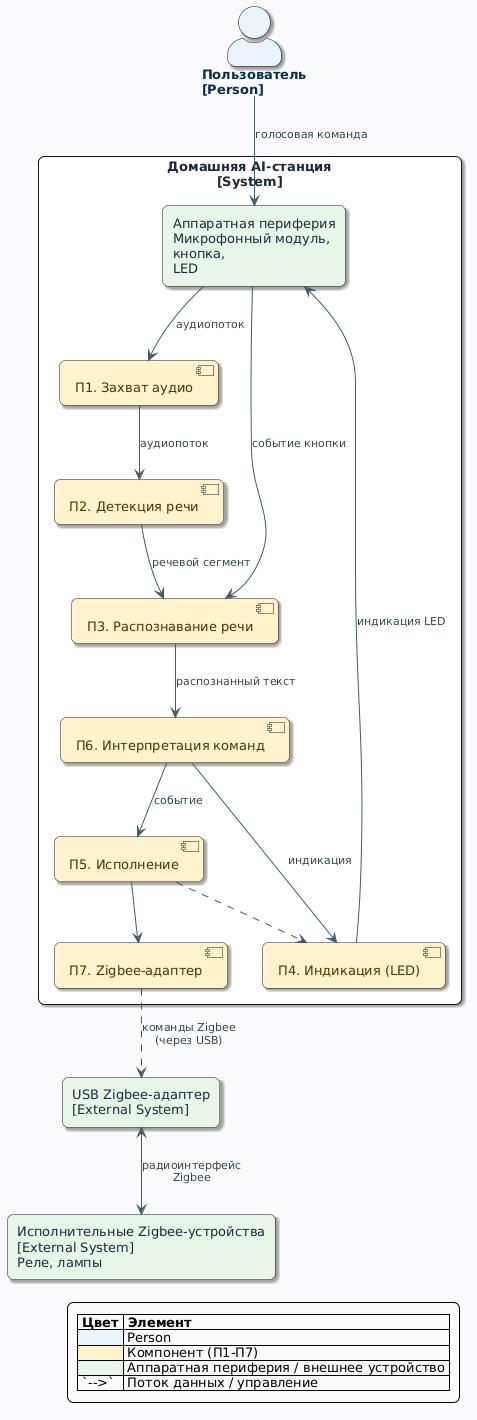
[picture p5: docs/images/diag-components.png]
Диаграмма компонент

Общая диаграмма компонент — код PlantUML: [diag-components.uml](./diagrams/diag-components.uml).

### 4.1. Требования к структуре

Система состоит из подсистем.

- П1. Подсистема записи речи: микрофонный модуль;
- П2. Подсистема детекции и предобработки речи;
- П3. Подсистема распознавания речи;
- П4. Подсистема индикации: LED на микрофонном модуле;
- 4.1 Соответствие фаз и светодиодов:
| Фаза | Светодиод | Режим |
|---|---|---|
| «слушаю» | — | все выключены |
| «распознаю» | LED-1 | постоянный |
| «команда» | LED-2 | 1с |
| «ошибка» | LED-3 | мигание |
- П5. Подсистема исполнения: сервисы systemd, журнал событий;
- П6. Подсистема интерпретации команд: сопоставляет распознанный текст со словарём; порождает событие управления; передаёт событие в П7;
- П7. Подсистема управления Zigbee: взаимодействие с USB-адаптером Zigbee;

### 4.2. Функциональные требования (Functional Requirements, FR)

### 4.2.1 Общие требования:

- FR-1.1. Система должна записывать речь через микрофонный модуль;

### 4.2.2 Требования к записи речи и распознаванию:

- FR-2.1. Подсистема захвата аудио (П1) должна непрерывно захватывать аудиопоток с выбранного входа;
- FR-2.2. Подсистема детекции речи (П2) должна выделять речевые сегменты в аудиопотоке;
- FR-2.3. Подсистема распознавания речи (П3) должна выдавать транскрипт речевых сегментов в реальном времени;
- FR-2.4. Система должна применять модуль программного усиления речи;

### 4.2.3 Требования к голосовому управлению:

- FR-3.1. Система должна содержать словарь команд: каждая команда — шаблон распознаваемой фразы, сопоставленный действию;
- FR-3.2. Подсистема интерпретации команд (П6) должна нормализовывать распознанный текст и вычислять процент совпадения с командами словаря;
- FR-3.3. При проценте совпадения ниже порога подтверждения (80%) подсистема интерпретации команд (П6) должна игнорировать фразу;
- FR-3.4. При проценте совпадения выше порога подтверждения (80%) подсистема интерпретации команд (П6) должна создать событие управления;
- FR-3.5. При появления события управления Zegbee, подсистема интерпретации команд (П6) должна передать событие в подсистему управления Zegbee;
- FR-3.6. При получении события управления, подсистема управления Zigbee (П7) должна исполнить команду на целевом устройстве;
- FR-3.7. Система должна фиксировать каждое событие - команда, действие, сбой - в журнале с меткой времени;
- FR-3.8. Система должна подтверждать исполнение команды LED-индикацией (см. п.4.1);

### 4.2.4 Требования к управлению через кнопки:

- FR-4.1. Система должна активировать обновление прошивки при нажатии кнопки 1;

### 4.3. Нефункциональные требования (Non-Functional Requirements, NFR)

### 4.3.1 Требования к надёжности

- NFR-1.1. Система должна функционировать не менее 24 часов после запуска;
- NFR-1.2. При сбое сервиса подсистема исполнения (П5) должна автоматически перезапускать сервис средствами systemd;
- NFR-1.3. При зависании процесса Система должна перезапускать процесс;
- NFR-1.4. При потере питания Система должна сохранять целостность файловой системы и сохранённых данных;
- NFR-1.5. При отказе Zigbee-адаптера Система должна продолжать выполнять функции захвата аудио и распознавания;
- NFR-1.6. Система должна обеспечивать среднюю наработку на отказ не менее 720 ч непрерывной работы;

### 4.3.2 Требования безопасности

- NFR-2.1. Система должна обрабатывать данные локально;
- NFR-2.2. Система должна ограничивать сетевой доступ;
- NFR-2.3. Система должна исполнять сервисы под выделенной учётной записью (не root), если сервис не требует привилегии;
- NFR-2.4. Система должна ограничивать привилегии сервисов конфигурацией sudoers;
- NFR-2.5. Система должна запретить ложные срабатывания на произвольную речь;
- NFR-2.6. Система должна запретить SSH-доступ: сервис openssh выключён; порт 22 закрыт; аутентификация SSH запрещена;
- NFR-2.8. Система должна запретить все входящие соединения, кроме протокола Zegbee;

### 4.3.3 Требования к интерфейсам

- NFR-3.1. Система должна предоставлять пользователю визуальную индикацию для фаз: «слушаю», «команда», «готово», «ошибка»;
- NFR-3.2. При нажатии пользователем кнопки Система должна выполнять назначенное действие;
- NFR-3.3. Система должна захватывать аудио с ALSA-карты (44,1/48 кГц);
- NFR-3.4. Система должна преобразовывать поток программно в 16 кГц моно для распознавания;

### 4.3.4 Требования к совместимости (аппаратной и программной)

- NFR-4.1. Система должна функционировать на платформе Orange Pi CM4 (SoC RK3566, 4×Cortex-A55) под ядром Linux 6.18;
- NFR-4.2. Система должна управлять исполнительными устройствами через USB Zigbee-адаптер;
- NFR-4.3. Система должна быть совместима с окружением Python 3;

### 4.3.5 Требования к производительности

- NFR-5.1. Подсистема распознавания речи (П3) должна распознавать речевой сегмент с задержкой не более 2-кратной длительности сегмента;
- NFR-5.2. Система должна распознавать тихую речь с дистанции не менее 1 м с погрешностью менее 20%;
- NFR-5.3. Система должна распознавать громкую речь — до 5 м с погрешностью менее 20%;
- NFR-5.4. Система должна выполнять цикл «команда - исполнение» за время не более 10 с после окончания речи;

### 4.3.6 Требования к эксплуатации

- NFR-6.1. Система должна предоставлять средства диагностики для администратора;
- NFR-6.2. Система должна регистрировать рабочие события и сбои в журнале systemd;

### 4.3.7 Требования к документированию

- NFR-7.1. Документация проекта должна быть опубликована в репозитории проекта;
- NFR-7.2. Документация должна включать в состав: "Видение и границы", "SRS", "README", "CONTRIBUTING", "CHANGELOG", "Глоссарий";
- NFR-7.3. Документация должна быть оформлена в нотации Markdown;

### 4.3.8 Требования к конструкции

- NFR-8.1. Физические компоненты системы должны быть размещены в едином корпусе;
- NFR-8.2. Корпус должен вмещать компоненты: одноплатный компьютер Orange Pi CM4, микрофонный модуль ReSpeaker 2-Mic, плату с кнопками, интерфейс питания, шлейфы соединения, систему пассивного охлаждения;
- NFR-8.3. Корпус должен обеспечивать доступ к USB, питанию и кнопкам без разборки;
- NFR-8.4. Конструкция корпуса должна выдерживать падение с высоты 1 метр;

### 4.3.9 Требования к составу ПО и драйверам

- NFR-9.1. Система должна поддерживать архитектуру aarch64;
- NFR-9.2. Система должна поддерживать ядро 6.18.x;
- NFR-9.3. В Системе должны быть установлены пакеты: systemd, NetworkManager, wpa_supplicant, openssh-server, python3; виртуальное окружение KWS (vosk 0.3.45, onnxruntime ≥ 1.23.2, numpy ≥ 2.5, cffi, requests, tqdm, srt, gpiod ≥ 2.5, spidev);
- NFR-9.4. В системе должны быть установлены драйверы: brcmfmac; snd-soc-wm8960 (ReSpeaker 2-Mic HAT); spidev3.0; libgpiod;
- NFR-9.5. В системе должны быть установлены прошивки: brcmfmac43456-sdio.bin|.txt|.clm_blob;

## 5. Порядок контроля и приёмки Системы

### 5.1. Виды испытаний

- Приёмо-сдаточные проверки выполняются по приёмочным тестам;
- Аудио-тракт (запись звука) проверяется замерами;
- Расшифровка речи проверяется на эталонных записях (тихая речь, несколько голосов, команды);

### 5.2. Приёмочные тесты (TC: Test case)

- ТC-01. Сценарий «громкая речь на расстоянии»: речь с 3 м распознаётся;
- ТC-02. Команда «включи свет»  активирует устройство Zigbee, журнал содержит событие;
- ТC-03. Произвольная речь вне словаря команд не активирует устройство Zigbee;
- ТC-04. После перезагрузки устройства происходи перезапуск служебных сервисов;
- TC-05. Корпус первого релиза соответствует требованиям;
- TC-06. Адрес устройства не обнаружен в локальной сети;
- TC-07. Состав ПО - пакеты, драйвера - соответствует требованиям;

## 6. Требования к документированию Системы (перечень документов)

- Документация требований: [docs/vision-ru.md](./vision-ru.md),
  [docs/srs-ru.md](./srs-ru.md);
- аппаратная документация: [docs/hardware-ru.md](./hardware-ru.md),
  [docs/glossary-ru.md](./glossary-ru.md);
- программная документация: спецификации возможностей ([openspec/specs/](../openspec/specs/)),
  скрипты и сервисы (см. README);
- процессные документы: CONTRIBUTING.md, CHANGELOG.md;

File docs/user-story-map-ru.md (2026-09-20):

# Карта пользовательских историй (User Story Map)

Версия документа: 0.1
Дата: 2026-09-12
Статус: черновик
Связанные документы: [Видение и границы](./vision-ru.md), [SRS](./srs-ru.md), [Бэклог](./backlog-ru.md)

## 1. Назначение

Карта показывает пользовательские сценарии станции слева направо (скелет)
и истории под ними сверху вниз (по мере детализации). Горизонтальная линия —
MVP-срез: истории над линией проверяют гипотезу продукта.

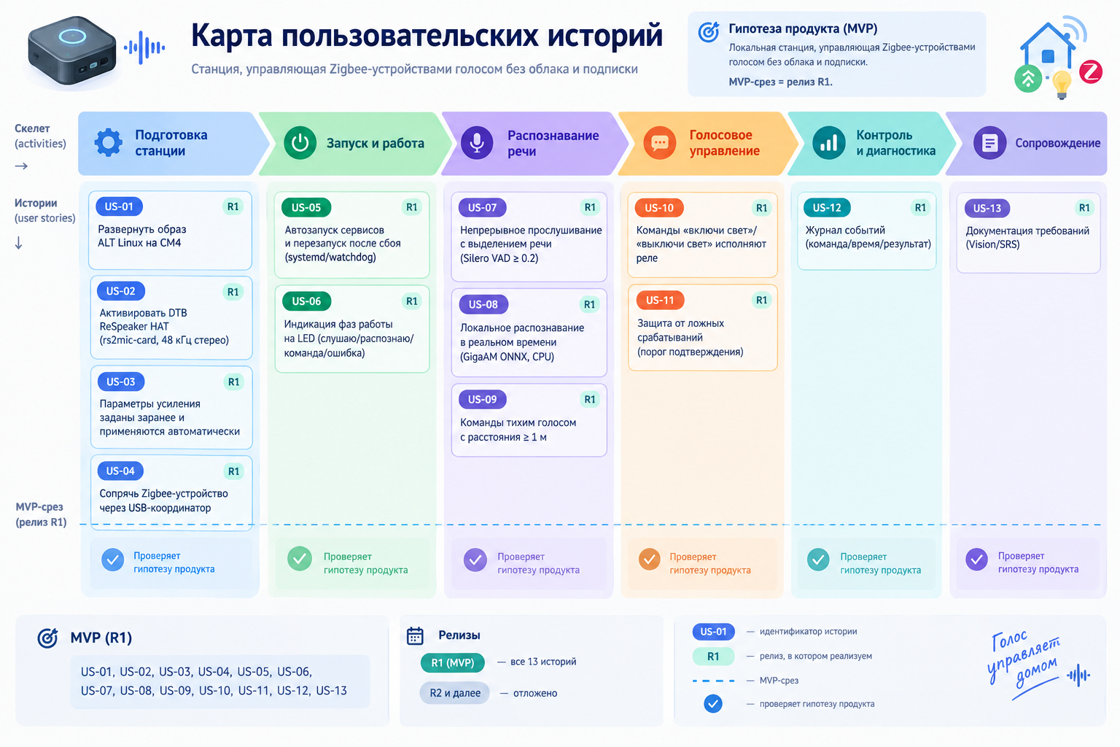
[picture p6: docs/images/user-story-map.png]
Диаграмма карты пользовательских историй


## 2. Гипотеза продукта (MVP)

Пользователю нужна локальная станция, управляющая Zigbee-устройствами
голосом без облака и подписки. MVP-срез = релиз R1.

## 3. Скелет (activities)

Подготовка станции → Запуск и работа → Распознавание речи →
Голосовое управление → Контроль и диагностика → Сопровождение

## 4. Карта историй

### Подготовка станции
- US-01 Развернуть образ ALT Linux на CM4 — R1
- US-02 Активировать DTB ReSpeaker HAT (rs2mic-card, 48 кГц стерео) — R1
- US-03 Параметры усиления заданы заранее и применяются автоматически — R1
- US-04 Сопрячь Zigbee-устройство через USB-координатор — R1

### Запуск и работа
- US-05 Автозапуск сервисов и перезапуск после сбоя (systemd/watchdog) — R1
- US-06 Индикация фаз работы на LED (слушаю/распознаю/команда/ошибка) — R1

### Распознавание речи
- US-07 Непрерывное прослушивание с выделением речи (Silero VAD ≥ 0.2) — R1
- US-08 Локальное распознавание в реальном времени (GigaAM ONNX, CPU) — R1
- US-09 Команды тихим голосом с расстояния ≥ 1 м — R1

### Голосовое управление
- US-10 Команды «включи свет»/«выключи свет» исполняют реле — R1
- US-11 Защита от ложных срабатываний (порог подтверждения) — R1

### Контроль и диагностика
- US-12 Журнал событий (команда/время/результат) — R1

### Сопровождение
- US-13 Документация требований (Vision/SRS) — R1

## 5. MVP-срез и релизы

- R1 (MVP): US-01, US-02, US-03, US-04, US-05, US-06, US-07,
  US-08, US-09, US-10, US-11, US-12, US-13
- R2 и далее — отложено

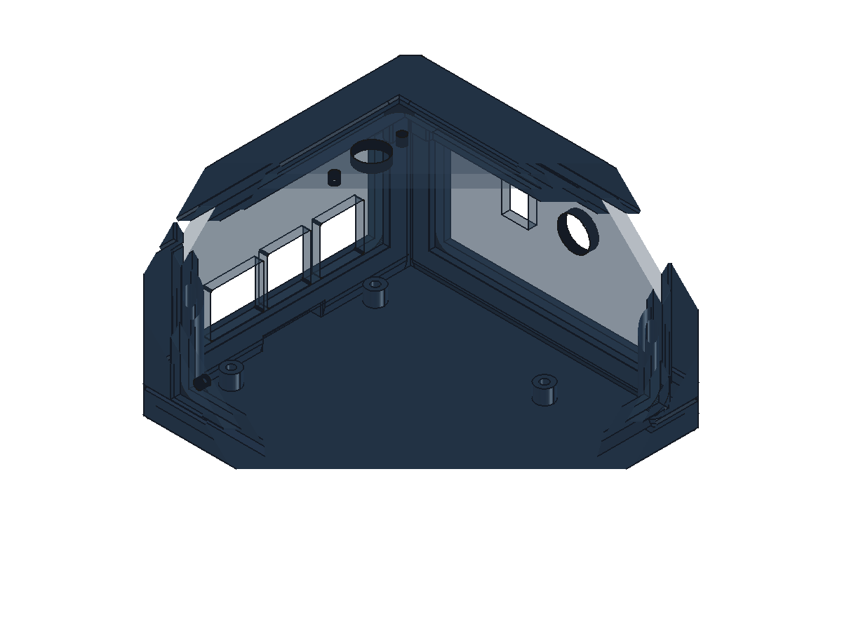
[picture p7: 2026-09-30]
mechanical/impulsar-01-rev06/cad/preview.png

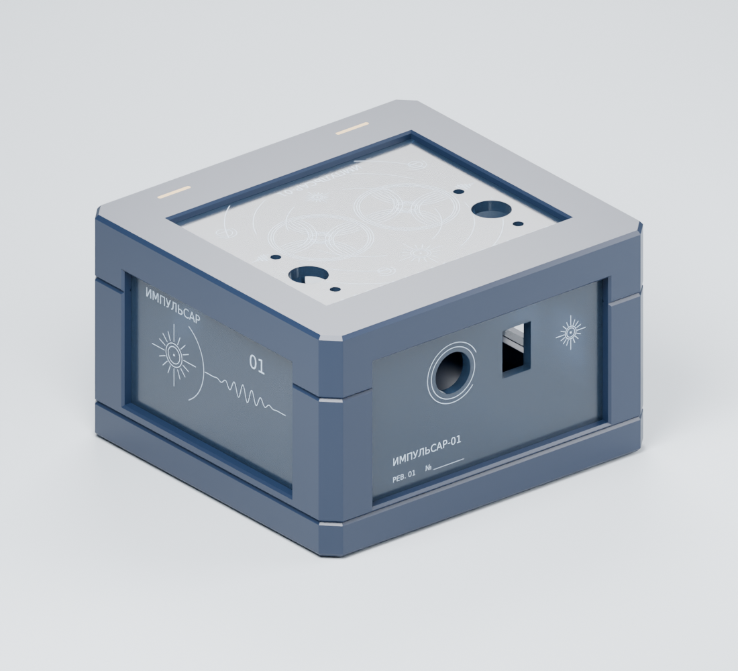
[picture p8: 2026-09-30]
mechanical/impulsar-01-rev06/previews/rear_right.png

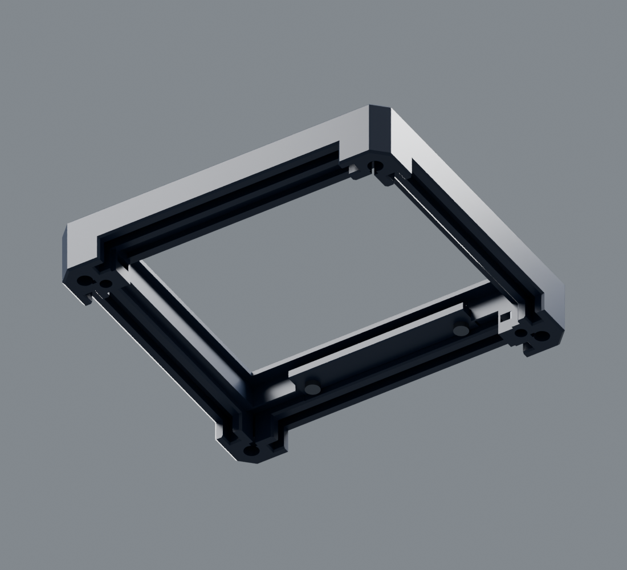
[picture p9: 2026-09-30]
mechanical/impulsar-01-rev06/previews/lid_underside.png

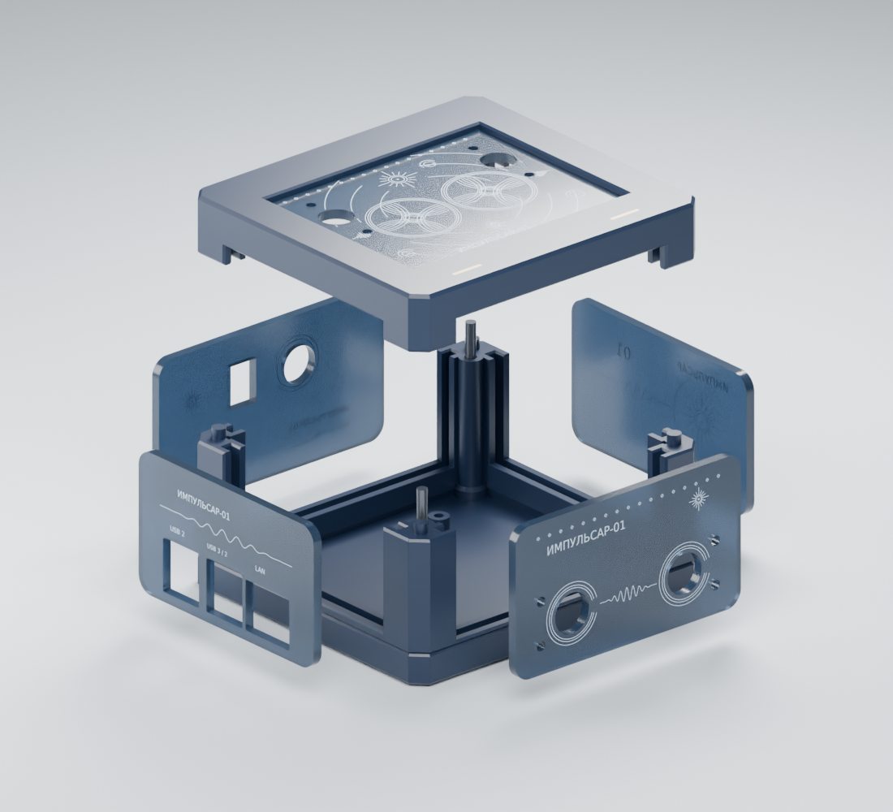
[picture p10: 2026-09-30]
mechanical/impulsar-01-rev06/previews/exploded.png

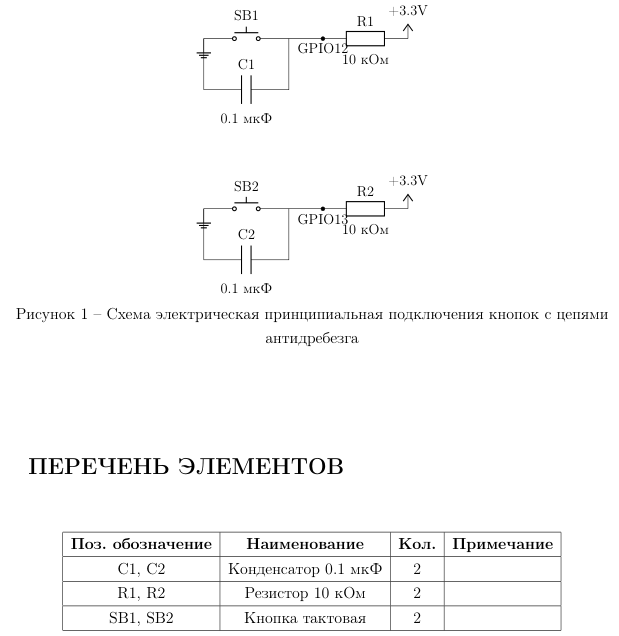
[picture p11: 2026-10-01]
electrical/buttons.png

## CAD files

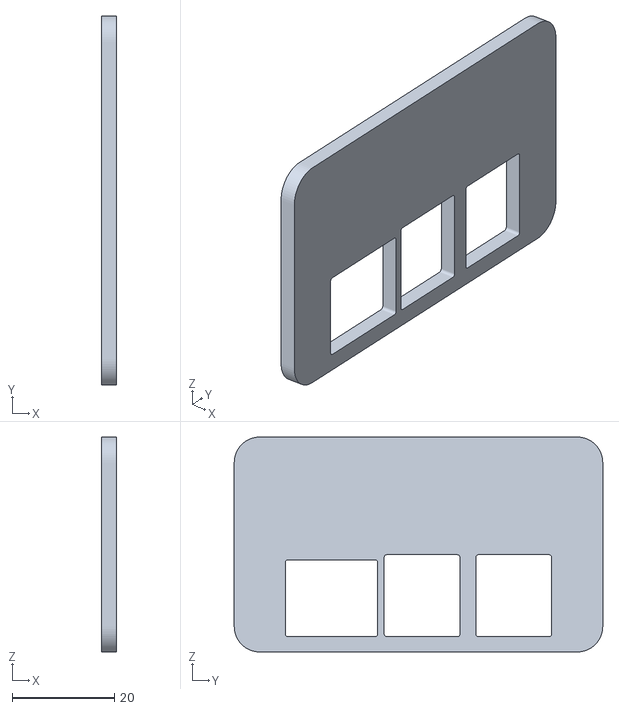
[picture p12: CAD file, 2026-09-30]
mechanical/impulsar-01-rev06/assembly/left_acrylic_assembly.stl
2.85 x 72.0 x 42.0

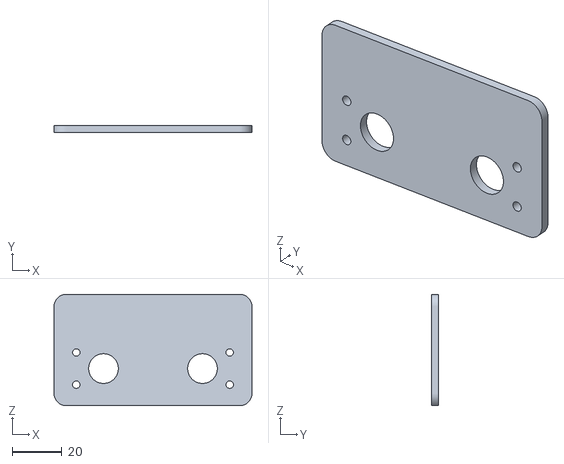
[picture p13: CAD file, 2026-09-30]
mechanical/impulsar-01-rev06/assembly/front_acrylic_assembly.stl
80.0 x 2.85 x 45.0

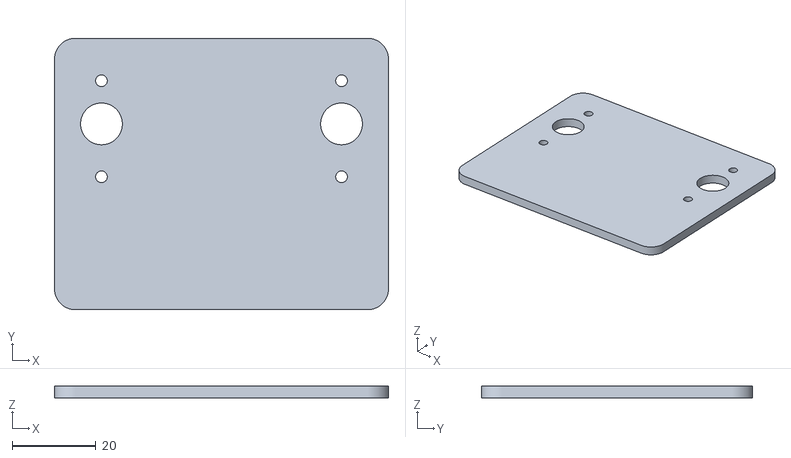
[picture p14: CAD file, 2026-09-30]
mechanical/impulsar-01-rev06/assembly/top_acrylic_assembly.stl
80.0 x 65.0 x 2.85

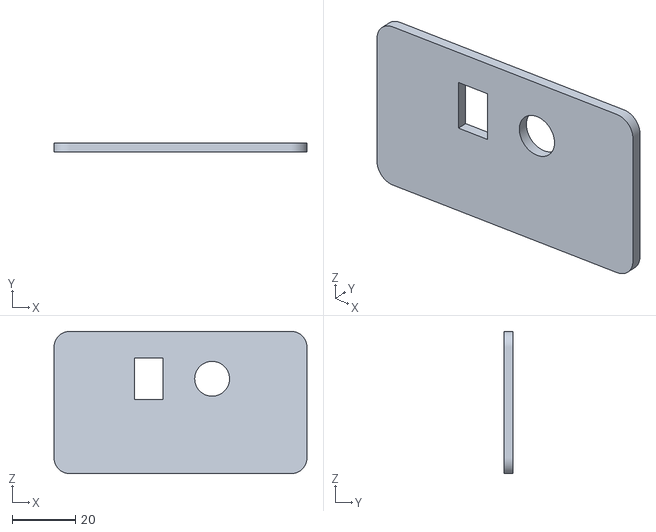
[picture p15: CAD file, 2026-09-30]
mechanical/impulsar-01-rev06/assembly/rear_acrylic_assembly.stl
80.0 x 2.85 x 45.0

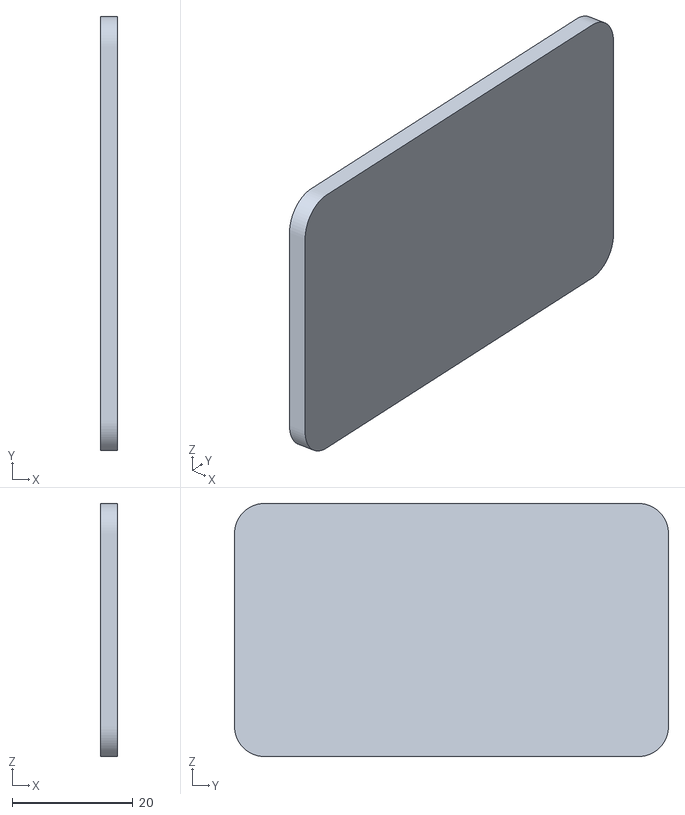
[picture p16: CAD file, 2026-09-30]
mechanical/impulsar-01-rev06/assembly/right_acrylic_assembly.stl
2.85 x 72.0 x 42.0

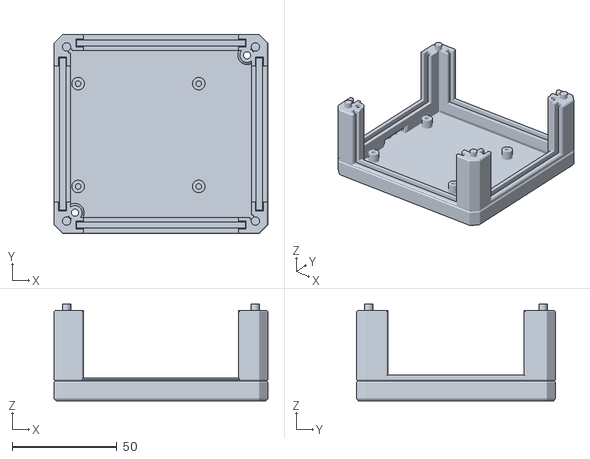
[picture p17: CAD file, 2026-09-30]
mechanical/impulsar-01-rev06/assembly/body.stl
102.0 x 95.0 x 46.0

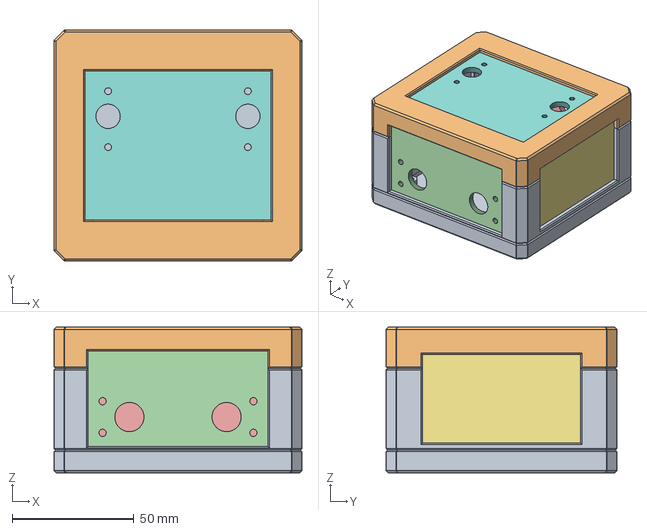
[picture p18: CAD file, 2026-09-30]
mechanical/impulsar-01-rev06/cad/step/enclosure.step
102.0 x 95.0 x 60.0 mm

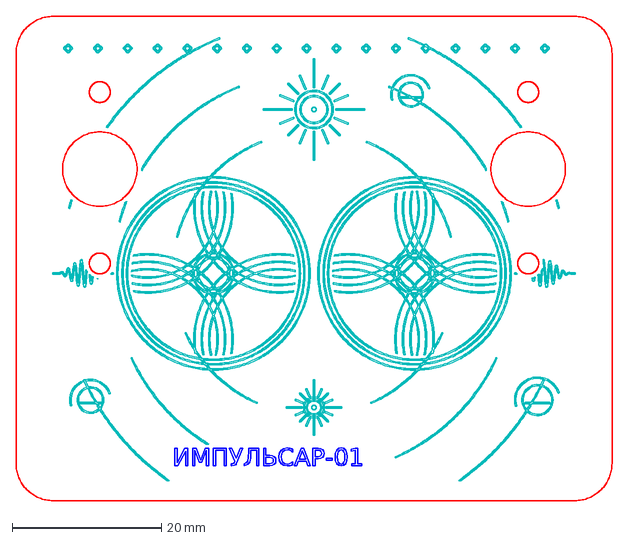
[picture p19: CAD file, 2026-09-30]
mechanical/impulsar-01-rev06/laser/top_2p85.dxf
80.0 x 65.0 mm

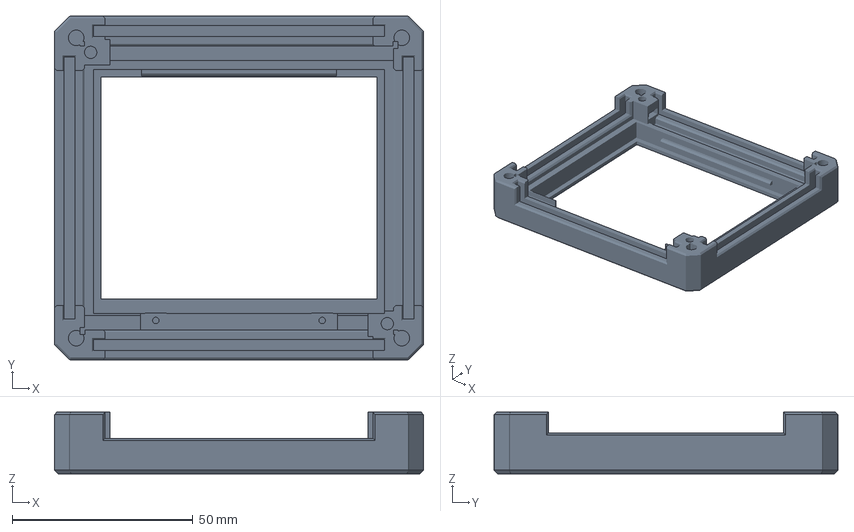
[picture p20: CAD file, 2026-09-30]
mechanical/impulsar-01-rev06/multicolor/lid_multicolor.3mf
102.0 x 95.0 x 17.0 mm

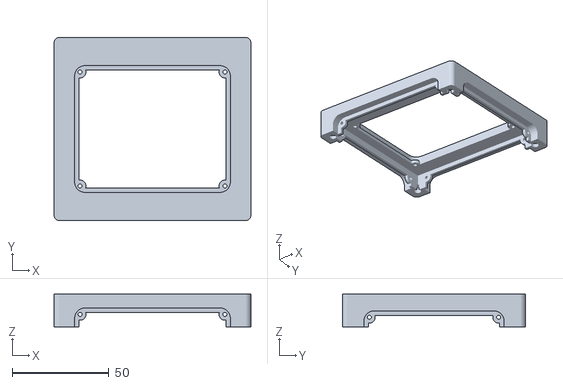
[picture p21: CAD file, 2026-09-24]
mechanical/impulsar-01-rev06/source/Corpus_paz_top.stl
102.0 x 95.0 x 17.0

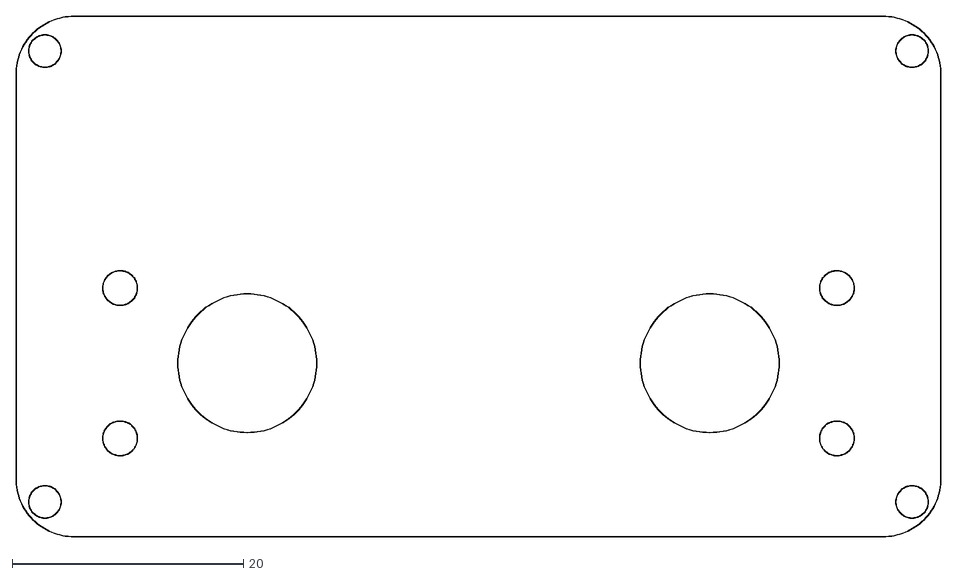
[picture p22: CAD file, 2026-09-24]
mechanical/Northern lights - 01/front.dxf
80.0 x 45.0

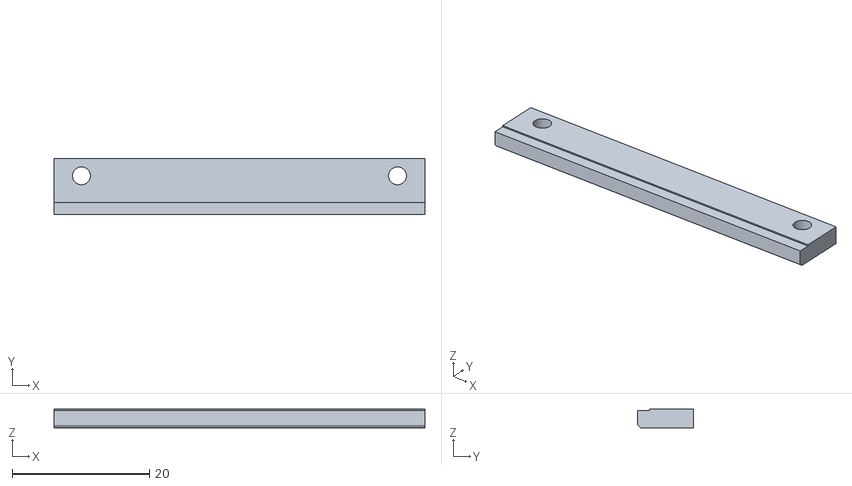
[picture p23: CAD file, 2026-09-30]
mechanical/impulsar-01-rev06/cad/print/glazing_bar_print.stl
54.0 x 8.10 x 2.70

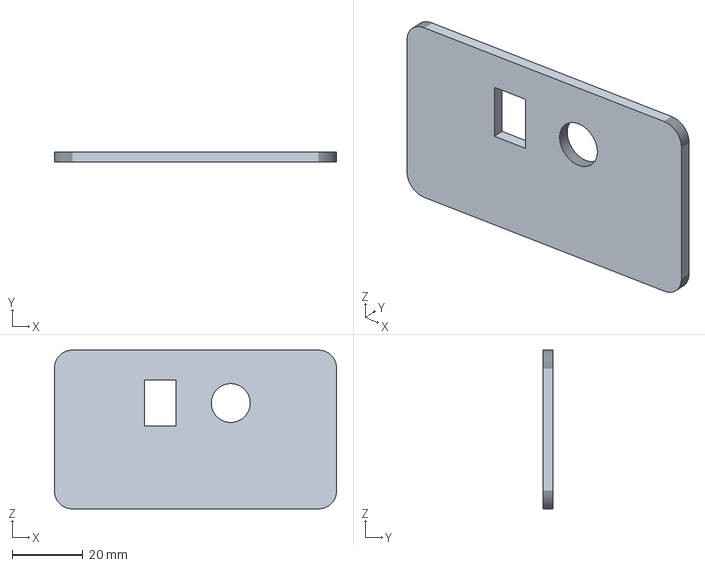
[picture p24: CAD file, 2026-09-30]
mechanical/impulsar-01-rev06/cad/step/rear_acrylic.step
80.0 x 2.85 x 45.0 mm

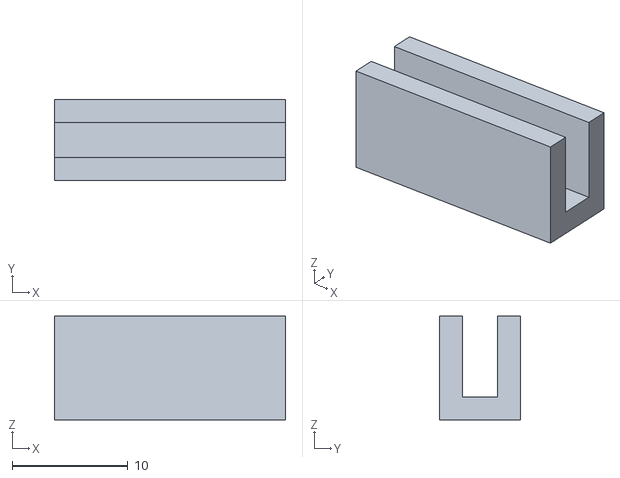
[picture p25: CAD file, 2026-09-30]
mechanical/impulsar-01-rev06/coupons/groove_3.05_print.stl
20.0 x 7.05 x 9.00

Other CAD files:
mechanical/impulsar-01-rev06/cad/assembly/right_acrylic.stl
mechanical/impulsar-01-rev06/cad/print/body_print.stl
mechanical/impulsar-01-rev06/cad/assembly/top_acrylic.stl
mechanical/impulsar-01-rev06/laser/kerf_coupon.dxf
mechanical/Northern lights - 01/left_panel(usb).dxf
mechanical/Northern lights - 01/rear.dxf
mechanical/Northern lights - 01/right.dxf
mechanical/Northern lights - 01/top.dxf
mechanical/impulsar-01-rev06/assembly/glazing_bar.stl
mechanical/impulsar-01-rev06/assembly/lid.stl
mechanical/impulsar-01-rev06/cad/assembly/body.stl
mechanical/impulsar-01-rev06/cad/assembly/front_acrylic.stl
mechanical/impulsar-01-rev06/cad/assembly/glazing_bar.stl
mechanical/impulsar-01-rev06/cad/assembly/left_acrylic.stl
mechanical/impulsar-01-rev06/cad/assembly/lid.stl
mechanical/impulsar-01-rev06/cad/assembly/rear_acrylic.stl
mechanical/impulsar-01-rev06/cad/enclosure.FCStd
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

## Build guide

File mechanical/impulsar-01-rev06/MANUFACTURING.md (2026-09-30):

# Импульсар-01 / 06

Акрил **2,85 мм**, пазы **3,00 мм**,
верхняя панель под съёмной планкой, две половины на винтах снизу.
Состав варианта и генерация моделей описаны в [README](README.md).

Корпус

## Геометрия варианта

| Параметр | rev06 |
| --- | --- |
| Габарит корпуса | 102 × 95 × 60 мм |
| Толщина всех пяти панелей | 2,85 мм |
| Ширина боковых пазов | 3,00 мм: суммарный зазор 0,15 мм |
| Высота обоих пазов верхнего акрила | 3,00 мм: суммарный зазор 0,15 мм |
| Верхний акрил в сборке | Z=55,075…57,925 мм |
| Контактные поверхности верхних пазов | Z=55 / 58 мм |
| Фаски стыка / глубина нижней V-канавки | одинаковые 0,60 мм |
| Высота каждой декоративной линии | 1,32 мм номинально, без сборочного зазора стыка |
| Основные печатные детали | основание, рамка, прижимная планка: 3 детали |

Передний паз верхнего акрила встроен в рамку. Задний образуется рамкой и
прикрученной планкой. Планка упирается в пластиковые площадки: затяжка не должна
прижимать акрил. Отверстий под крепёж в акриле нет.
Окно верхней рамки прямоугольное, без скруглений углов, с фаской 0,6 мм по кромке.
Габарит проёма под фаской — 76,4 × 61,4 мм; контур самого акрила сохранён.
Защёлки и их штифты исключены, исходные установочные штифты половинок сохранены.

В основании внутренние плоские поверхности стенок отодвинуты наружу на **0,5 мм
с каждой стороны**, начиная от поверхности дна Z=2,5 мм. Между противоположными
прямыми участками теперь **86,4 × 79,4 мм** вместо 85,4 × 78,4 мм. Это расстояние
между стенками, а не свободный прямоугольник через угловые стойки. Стойки платы,
усиления винтов и пазы акрила сохранены; толщина внутренней стенки рядом с пазом
теперь 2,15 мм. Фактическую посадку платы проверить после печати.

## Крепёж: что купить

| Количество | Наименование | Назначение |
| ---: | --- | --- |
| 2 | **Винт M3×50, DIN 912 / ISO 4762**, цилиндрическая головка, внутренний шестигранник | Соединение половинок |
| 2 | **Гайка M3, DIN 934**, обычная шестигранная, размер под ключ 5,5 мм, высота 2,4 мм | Боковые карманы верхней рамки |
| 2 | **Саморез ST2,2×6,5, DIN 7981**, полукруглая головка, крестовой шлиц | Планка верхнего акрила |

Длина винтов и саморезов указана **под головкой**. Не заменять гайки высокими
самоконтрящимися и саморезы потайными: посадки рассчитаны на указанные формы.
Для покупки удобно взять по 4 штуки каждого крепежа — с запасом на пробники.
Обычно потребуются шестигранник 2,5 мм и отвёртка PH1; шлиц сверить при покупке.

Это соединение обходится без термовставок и паяльника. Винты M3 работают с
металлическими гайками при каждом открытии корпуса. Саморезы используются только
для менее частого снятия верхнего акрила.

### Посадки и доступ

- Оси винтов M3: **XY=(10; 10) и (92; 85)**, диагонально противоположные углы.
- Проходные отверстия Ø3,4 мм. Головка винта Ø5,5 × 3 мм утоплена на 0,3 мм.
- Все четыре исходных углубления под ножки сохранены **Ø10 × 2 мм**.
  В двух винтовых углах добавлена только локальная выборка **Ø6 мм до глубины
  3,3 мм** по оси винта. Она частично выходит за контур исходного углубления.
  Над головкой добавлена сплошная опорная перемычка толщиной **1,7 мм** вокруг
  проходного отверстия; боковая стенка выборки — не менее **1,4 мм**.
- Гайки входят в боковые карманы изнутри снятой рамки, через небольшие удерживающие
  выступы. Плоские стенки не дают гайке провернуться. Продвинуть гайку до упора и
  совместить её резьбу с осью винта. Удержание выступами проверить на реальной гайке.
- Гайка занимает Z=46,6…49,0; конец затянутого M3×50 находится на Z=53,3,
  до дна глухого отверстия остаётся 1 мм. Резьба винта проходит всю высоту гайки.
- У планки проходные отверстия Ø2,6 мм, в рамке направляющие Ø1,8 мм.
  Толщина планки у крепежа 2,7 мм, номинальное заглубление самореза — 3,8 мм.
  До наружной поверхности крышки от конца самореза остаётся 1 мм.
- Если устанавливать мягкие ножки поверх головок M3, две из них придётся снимать
  для разборки. Ножки не входят в комплект моделей.

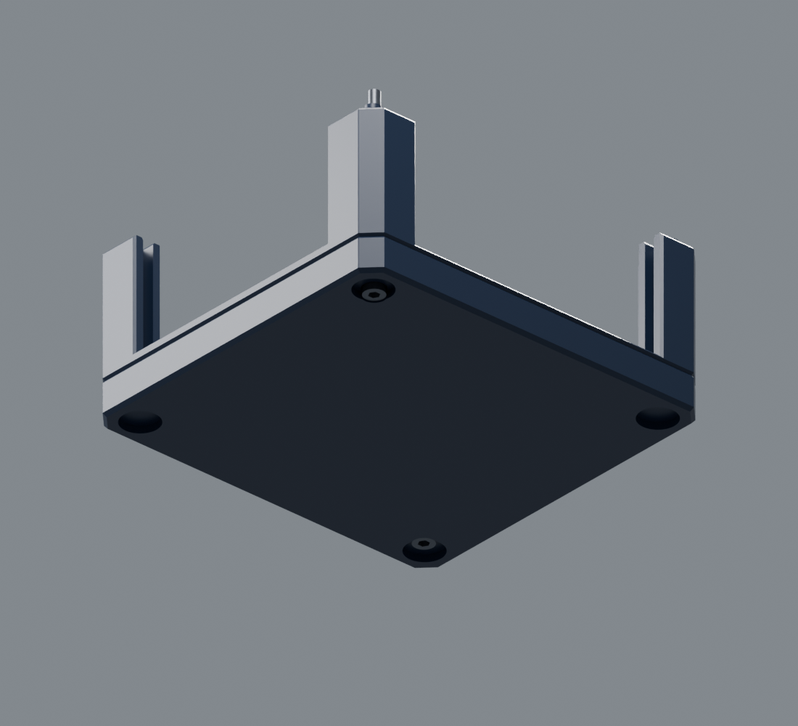
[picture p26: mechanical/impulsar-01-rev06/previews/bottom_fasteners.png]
Крепёж снизу


## Экспорты и ориентации деталей

| Файл | Количество |
| --- | ---: |
| [print/body_print.stl](print/body_print.stl) | 1 |
| [print/lid_print.stl](print/lid_print.stl) | 1 |
| [print/glazing_bar_print.stl](print/glazing_bar_print.stl) | 1 |

Сохранять ориентации файлов: рамка наружной стороной на стол, планка плоской
стороной на стол. Детали `assembly/` имеют координаты сборки и не предназначены
для прямой отправки на печать.

Модели заданы в миллиметрах. Масштабирование меняет расчётные посадки и зазоры;
для их изменения следует использовать параметры генератора.

**У рамки нужна локальная поддержка под нижней полкой переднего паза.**
В печатной ориентации это полоса X=24…78, Y=78,5…80,2, Z=5 мм.
Под полкой находится наружный бортик рамки, поэтому поддержка этой поверхности
должна опираться на модель.
Сначала отработать снятие поддержки на `fixed_groove_print.stl`; после снятия
поверхности паза должны остаться ровными, без остатков интерфейсного слоя.

Остальные предусмотренные горизонтальные поверхности:
- карманы гаек печатаются мостами шириной до **5,7 мм**;
- исходные углубления под ножки — **10 мм**, локальные выборки под головки — **6 мм**;
- исходное нижнее служебное отверстие — мост до **21 мм**.

Эти участки и посадки представлены отдельными пробниками; технологические
параметры изготовления подбираются отдельно от геометрической модели.

### Многоцветная геометрия

[multicolor/lid_multicolor.3mf](multicolor/lid_multicolor.3mf) содержит рамку и два
золотистых акцента как **один объект с тремя частями** в общей системе координат.
Основной цвет — тёмно-синий; толщина декоративных вставок — 0,40 мм.
Файл хранит геометрию и цвета, без профиля оборудования. Взаимное положение частей
должно сохраняться; поддержка переднего паза нужна так же, как для одноцветной рамки.

## Сначала пробники

1. `coupons/groove_2.95_print.stl`, `groove_3.00_print.stl`, `groove_3.05_print.stl`:
   проверить реальный лист. Номинальный корпус использует **3,00 мм**.
2. `coupons/actual_groove_print.stl`: проверить настоящий участок бокового паза,
   включая заход и наружный профиль.
3. `coupons/fixed_groove_print.stl`: проверить поддержку и посадку верхней панели.
4. `coupons/bar_mount_print.stl` + `bar_end_print.stl` и ST2,2×6,5:
   проверить нарезание резьбы саморезом и посадку планки на упор.
5. `coupons/nut_corner_print.stl`: проверить установку гайки и удерживающие выступы.
6. `coupons/bolt_lower_corner_print.stl` + `bolt_upper_corner_print.stl`:
   полноценный угол с исходным установочным штифтом, гайкой и M3×50.
   После печати верхний фрагмент перевернуть в сборочное положение и состыковать
   по штифту; пробник проверяет реальную длину винта и доступ к головке.
7. `coupons/cm4_trial_print.stl`: примерить окна к разъёмам платы.

Гайки и саморезы проверить до печати рамки. Саморезы затягивать вручную до контакта
планки с упорами. Если посадка акрила окажется тесной, изменить `groove_width_mm` в
`design.json` и пересобрать, вместо силового вдавливания стекла.
`parameters.json` в результатах — отчёт о параметрах, сборщик его перезаписывает.

## Лазер: контуры и гравировка

Все пути резки и гравировки корпуса находятся в каталоге `laser/`.
Пять DXF имеют имена `*_2p85.dxf`, обозначающие толщину листа.
Надпись «Орбита импульса» отсутствует; центральные круги остаются только гравировкой.

| Панель | Габарит, мм | Файл |
| --- | --- | --- |
| Передняя | 80 × 45 | [front_2p85.dxf](laser/front_2p85.dxf) |
| Левая, CM4 | 72 × 42 | [left_2p85.dxf](laser/left_2p85.dxf) |
| Задняя | 80 × 45 | [rear_2p85.dxf](laser/rear_2p85.dxf) |
| Правая | 72 × 42 | [right_2p85.dxf](laser/right_2p85.dxf) |
| Верхняя | 80 × 65 | [top_2p85.dxf](laser/top_2p85.dxf) |

Толщина всех панелей — **2,85 мм**. Размеры — габариты фигурных контуров, а не
размеры прямоугольных заготовок. [Общий SVG](laser/layout.svg) — 1:1, миллиметры,
без компенсации ширины реза. `CUT_OUTER` и `CUT_INNER` — резка;
`ENGRAVE_LINES` и `ENGRAVE_FILL` — **заливная гравировка замкнутых контуров**.
Порядок обработки: гравировка, внутренние вырезы, внешний контур.

Окна CM4 по-прежнему оценены по фотографии; размер и привязку нужно проверить
на установленной плате. Тонкая перемычка между окнами — 1,3 мм.

## Сборка

1. Удалить поддержки и проверить каналы. Установить две гайки в карманы рамки.
2. Держать снятую рамку внутренней стороной вверх. Планку пока не ставить.
3. Подать верхний акрил в рамку **параллельно ей**, сместив кромку к задней стороне
   на 1,8 мм относительно конечного положения. Дополнительный карман даёт место
   для такого захода.
4. Сдвинуть акрил на 1,8 мм к передней стороне, завести кромку в неподвижный паз.
5. Установить заднюю планку и два ST2,2×6,5. Акрил должен удерживаться с небольшим
   зазором; планка при этом касается пластиковых упоров.
6. Установить четыре боковые панели в основание, затем надеть рамку по исходным
   установочным штифтам.
7. Вставить два M3×50 снизу и попеременно подтянуть вручную до смыкания половинок.
   Гайки должны быть совмещены с винтами; усилием не протягивать несоосный крепёж.

Разборка выполняется в обратном порядке. Для снятия рамки достаточно двух M3;
саморезы планки трогать не требуется.

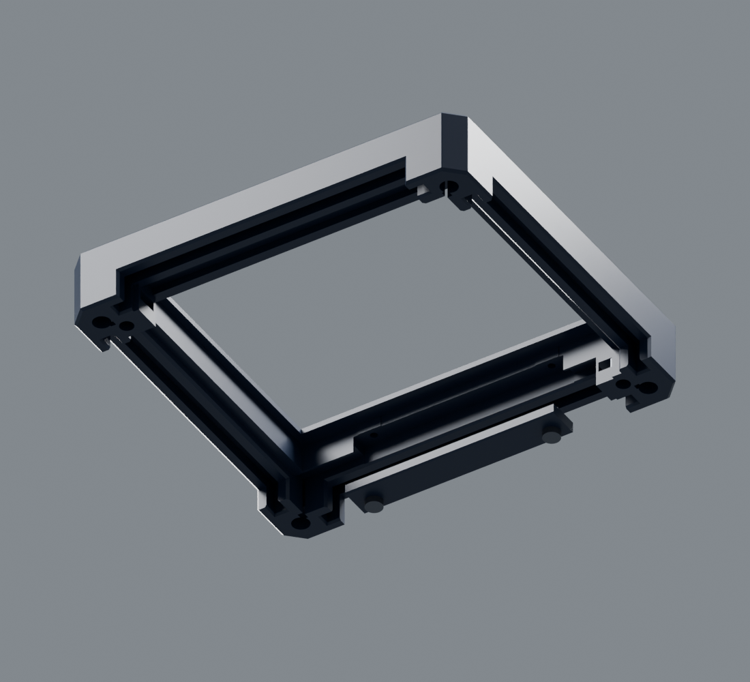
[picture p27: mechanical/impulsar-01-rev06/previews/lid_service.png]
Крышка и снятая планка


## Проверка и пересборка

Команды автономной пересборки и проверки приведены в [README](README.md).
[Отчёты проверки](validation/README.md) фиксируют сопряжения и движения панелей,
заход гаек, проход крепежа и отвёртки, состояние сеток, соответствие CAD контрольной
геометрии и контрольные суммы комплекта.

Резьбы крепежа представлены номинальными огибающими. Пересечение самореза с
направляющим отверстием и малый натяг гайки на входных выступах ожидаемы и записаны
отдельно. Цифровая проверка не устанавливает усилие затяжки, прочность резьбы материала,
ресурс или фактическую посадку после печати. Полная плата с компонентами внутри
корпуса не моделировалась; тепловые испытания не проводились.

[3D-сборка](assembly/impulsar06.glb) · [Вид снизу крышки](previews/lid_underside.png)
· [Разнесённая сборка](previews/exploded.png)

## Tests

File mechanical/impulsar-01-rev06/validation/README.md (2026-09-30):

# Проверка корпуса Импульсар-01 rev06

Проверено 28 сентября 2026 года на ALT Linux, Python 3.14.7, FreeCAD 1.1.3.
Версии Python-зависимостей закреплены в [requirements.txt](../requirements.txt).
Сборка STL повторена в отдельном виртуальном окружении из этих зависимостей.
Самодостаточность дополнительно проверена на копии только каталога варианта
вне репозитория: пересборка STL, пробников и многоцветного 3MF, извлечение сечений,
проверка исходников и повторное открытие готовых FCStd/STEP прошли успешно.
Входные данные находятся внутри варианта, результаты создаются в его `build/`.

## Результаты

| Проверка | Результат |
| --- | --- |
| Целостность готового комплекта | Все 44 файла соответствуют контрольным суммам rev06 |
| Сохранность базовых моделей | Два STL из `source/` соответствуют контрольным суммам в `reference/source.sha256.json`; лазерные DXF входят в контрольный комплект |
| Производственные сетки | 22 STL замкнуты, согласованно ориентированы и однокомпонентны |
| Автономная пересборка STL | Симметрическая разность с исходником менее 0,01 мм³ для каждой из восьми деталей |
| Сопряжения и дискретные траектории | 215 проверок пройдено для пересобранных STL и для экспортов CAD |
| Нативная CAD | Восемь деталей — валидные одиночные твёрдые тела; документ повторно открыт |
| STEP | Повторный импорт восьми деталей и сборки из восьми тел успешен; разница объёма каждой детали менее 0,001 мм³ |
| Редактирование FreeCAD | Изменены все пять размеров таблицы; после пересчёта все восемь деталей валидны и их объёмы изменились |

Разность CAD и исходного STL измерена как объём симметрической разности двух
твёрдых тел, а не просто разность их суммарных объёмов:

| Деталь | Разность, мм³ | Доля объёма исходника |
| --- | ---: | ---: |
| Основание | 4,857333 | 0,007623 % |
| Крышка | 0,323615 | 0,000757 % |
| Планка | 0,035417 | 0,003137 % |
| Каждая из пяти панелей | 0 | 0 % |

Круглые элементы нативной CAD аналитические, исходные STL полигональные;
представления не объявляются побайтно или геометрически идентичными.
Исходные производственные сетки сохранены в `../print/`, экспорты CAD — в `../cad/print/`.

Проверка редактирования использовала толщину акрила 2,80 мм, ширину паза 3,05 мм,
радиусы проходного отверстия 1,75 мм, направляющего отверстия самореза 0,95 мм
и отверстия планки 1,35 мм. Проверялась перестраиваемость дерева, а не пригодность
этого сочетания размеров для изготовления. Изменения не сохранены в готовом FCStd.

## Машиночитаемые отчёты

- [assets-verification.json](assets-verification.json) — контрольные суммы, базовые модели, сетки, многоцветный 3MF.
- [mesh-comparison.json](mesh-comparison.json) — пересобранная сеточная геометрия и исходник.
- [mesh-verification.json](mesh-verification.json) — сопряжения, траектории и намеренные натяги.
- [cad-construction.json](cad-construction.json) — валидность CAD-деталей и огибающих крепежа.
- [cad-verification.json](cad-verification.json) — STEP, сравнение, сопряжения, пересчёт параметров.
- [cad.sha256.json](cad.sha256.json) — контрольные суммы подготовленных CAD-файлов.

Команды повторения приведены в [README](../README.md). Отчёты здесь относятся к
подготовленному комплекту; результаты новых запусков записываются в игнорируемый
`build/`. Контрольные суммы и параметры базового комплекта лежат в `../reference/`.

**Физическая приёмка не выполнена.** Цифровые проверки не подтверждают посадку
реальных плат, лазерный керф, усадку печати, температурный режим или стойкость
к падению. Начинать изготовление следует с пробников из [инструкции](../MANUFACTURING.md).

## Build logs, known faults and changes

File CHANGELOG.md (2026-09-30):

# Changelog

Все заметные изменения в этом проекте будут документироваться в этом файле.

## [Unreleased]

### Added
- Корпус Импульсар-01 rev06 в `mechanical/impulsar-01-rev06`: самодостаточный каталог варианта с исходной геометрией, автономными генераторами STL и FreeCAD, STEP, многоцветным 3MF, пробниками посадок и цифровыми проверками. Физическая приёмка корпуса остаётся открытой.
- Инициализация проекта с OpenSpec workflow
- Базовая документация: README, CONTRIBUTING, CHANGELOG
- docs/ с документацией
- Документация проекта: видение и границы (`docs/vision.md`), ТЗ (`docs/srs.md`), дорожная карта (`docs/roadmap.md`); контекстная диаграмма, use case модель,SRS, ФТ/НФ
- Подготовка к публикации на GitHub: лицензия GPL-3.0; README с разделом «Documentation»; исходники диаграмм PlantUML вынесены в `docs/diagrams/`;

### Fixed
- Исправлена ссылка на фотографии прототипа в русской версии README.

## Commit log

2026-09-24 Update photo of prototype
2026-09-24 Add corpus files named - Norhtern lights
    [Corpus_paz_foot.stl, Corpus_paz_top.stl, front.dxf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]
2026-09-25 New folder for mechanical parts, including cases
    [Corpus_paz_foot.stl, Corpus_paz_top.stl, front.dxf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]
2026-09-30 Add self-contained rev06 enclosure with parametric FreeCAD models and manufacturing files (#2)
    * Add self-contained rev06 enclosure and FreeCAD models
    * Add repository guidance for coding agents
    [Corpus_paz_foot.stl, Corpus_paz_top.stl, actual_groove_print.stl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]
2026-09-30 Updated the case photo
2026-10-01 Added the first electrical circuit

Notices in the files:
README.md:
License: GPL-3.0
